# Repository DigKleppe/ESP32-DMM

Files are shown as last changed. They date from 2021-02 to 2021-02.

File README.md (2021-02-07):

# ESP32-DMM
6 digit DMM using ESP32 module
This DMM uses an ESP32 WRoom module as base of the system.
The ADC is a 24 bit ADS1256. The user interface is a 2.8'' TFT and 12 capacitive touchbuttons.
A frontend for voltage, current and Ohms completes the design.
The volts/ohms input is protected for 500V.
The current input has a fuse.

Specifications:
DC/AC true RMS, 10ME input resistance.
Voltage: 250mV - 500V 5 ranges;
Current: 10uA-10A 6 ranges;
Resistance: 1E - 20M, 5 ranges.

The accuracy is targetted at better than 0.1%.
Speed: for hi resolution ( 5-6 digits): 2 readings per second.
For lower resolutions 5 -10 readings per second.

Despite the use of some Aliexpress modules like the ADC ADS1256, it has become a
rather complex design. Not for beginners i suppose.

Remark about the resistors: 0.1% thin film resistors are used. These have better noise preformance.

One of the issues is calibrating, you need a accurate DVM for this.
The calibrating itself is done using a webserver. The calibration data can be up/downloaded
to a host. 

Status of the project 02-21:
Second version. New schematics and PCB, contains corrections of the first prototype. Also better screening to reduce noise.
Not tested yet.
Software: todo: make some changes io-ports.

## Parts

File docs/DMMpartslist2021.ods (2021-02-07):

Ref | Qnty | Value | Cmp name | Footprint | Description | Digikey | Mouser
ACDC1, | 1 | RAC10-15DK | RAC10-12DK | klp:RAC10 | Recom AC/DC converter 10W |  | 919-RAC10-05SK/277
ACDC2, | 1 | RAC10-05SK/277 | RAC10-12DK | klp:RAC10 | Recom AC/DC converter 10W |  | 919-RAC10-15DK/277
C1, C2, C9, C10, C15, C16, C17, C19, C20, C21, C23, C25, C26, C27, C29, C40, C41, C42, | 18 | 100n | C | Capacitor_SMD:C_0805_2012Metric_Pad1.15x1.40mm_HandSolder | Unpolarized capacitor
C11, C12, C30, C31, C36, | 5 | 1u | C | Capacitor_SMD:C_0805_2012Metric_Pad1.15x1.40mm_HandSolder | Unpolarized capacitor
C13, C14, C39, | 3 | 10uV16 | CP | Capacitor_THT:CP_Radial_D5.0mm_P2.00mm | Polarized capacitor
C32, | 1 | 2n2 Y2 | C | Capacitor_THT:C_Rect_L13.0mm_W4.0mm_P10.00mm_FKS3_FKP3_MKS4 | Unpolarized capacitor
C33, | 1 | 290p | C | Capacitor_THT:C_Disc_D3.0mm_W2.0mm_P2.50mm | Unpolarized capacitor
C37, | 1 | 10n | C | Capacitor_SMD:C_0805_2012Metric_Pad1.15x1.40mm_HandSolder | Unpolarized capacitor
C38, | 1 | 330p | C | Capacitor_SMD:C_0805_2012Metric_Pad1.15x1.40mm_HandSolder | Unpolarized capacitor
D1, D11, D12, D13, D16, D17, | 6 | BAT754S | BAT754S | klp:SOT-23-handsolder | Dual schottky barrier diode, in series, SOT-323 |  | 771-BAT754-T/R
D2, | 1 | CMKD6001 | Central_Semi_CMKD6001 | Package_TO_SOT_SMD:SOT-363_SC-70-6 | Ultra low leakage switching diode array 3 independent | 1514-CMKD6001TRPBFREECT-ND
D6, D7, | 2 | APT30DQ60KG | D | Package_TO_SOT_THT:TO-220-2_Vertical | Diode | 494-APT30DQ60KG
D8, D9, | 2 | G | LED_ALT | LED_SMD:LED_0805_2012Metric_Pad1.15x1.40mm_HandSolder | Light emitting diode, filled shape
D10, | 1 | 1.5SMC6.8A | Z3SMCxxx | Diode_SMD:D_SMC | 3000mW Zener Diode, SMC(DO-214AB)
F1, | 1 | PTCCL05H100SBE | Polyfuse | klp:PTCCL05H100SBE | Resettable fuse, polymeric positive temperature coefficient | BC3368-ND
F2, | 1 | Fuse | Fuse | Fuse:Fuseholder_Cylinder-5x20mm_Stelvio-Kontek_PTF78_Horizontal_Open | Fuse
J1, J2, J3, | 3 | Conn_01x01 | Conn_01x01 | klp:bananajack-5p | Generic connector, single row, 01x01, script generated (kicad-library-utils/schlib/autogen/connector/) |  |  | https://www.aliexpress.com/snapshot/0.html?orderId=3008924834401255&productId=32822244065
J4, | 1 | Conn_01x06 | Conn_01x04 | Connector_Phoenix_MSTB:PhoenixContact_MSTBVA_2,5_4-G_1x04_P5.00mm_Vertical | Generic connector, single row, 01x04, script generated (kicad-library-utils/schlib/autogen/connector/)
J5, | 1 | bozed header 6p | Conn_02x03_Odd_Even | Connector_IDC:IDC-Header_2x03_P2.54mm_Vertical | Generic connector, double row, 02x03, odd/even pin numbering scheme (row 1 odd numbers, row 2 even numbers), script generated (kicad-library-utils/schlib/autogen/connector/)
J6, J9, | 2 | boxed header 2x5 | Conn_02x05_Odd_Even | Connector_IDC:IDC-Header_2x05_P2.54mm_Vertical | Generic connector, double row, 02x05, odd/even pin numbering scheme (row 1 odd numbers, row 2 even numbers), script generated (kicad-library-utils/schlib/autogen/connector/)
J7, | 1 | Conn_01x06 | Conn_01x06 | Connector_PinHeader_2.54mm:PinHeader_1x06_P2.54mm_Vertical | Generic connector, single row, 01x06, script generated (kicad-library-utils/schlib/autogen/connector/)
J8, | 1 | Conn_02x10_Odd_Even | Conn_02x10_Odd_Even | Connector_IDC:IDC-Header_2x10_P2.54mm_Vertical | Generic connector, double row, 02x10, odd/even pin numbering scheme (row 1 odd numbers, row 2 even numbers), script generated (kicad-library-utils/schlib/autogen/connector/)
J12, | 1 | Conn_01x02 | Conn_01x02 | Connector_Phoenix_MSTB:PhoenixContact_MSTBVA_2,5_2-G_1x02_P5.00mm_Vertical | Generic connector, single row, 01x02, script generated (kicad-library-utils/schlib/autogen/connector/)
K2, | 1 | Coto 9104-05-10 | Coto_9104-05-10_SIL_reedrelay | klp:Relay_SPST_Coto_9104_SIL | Coto_9104-05-10_SIL reed relay, SPST, Closing Contact | 306-1193-ND
M1, | 1 | LTC1966module | LTC1966module | klp:ltc1966module | true RMS converter CJMCU-6668 |  |  | https://nl.aliexpress.com/item/4000428797754.html?spm=a2g0s.9042311.0.0.235b4c4dVnynwd
M2, | 1 | ADS1256module | ADS1256module | klp:ADS1256module |  |  |  | https://nl.aliexpress.com/item/32762202652.html?spm=a2g0s.9042311.0.0.235b4c4dVnynwd
Q1, Q2, Q3, Q4, Q5, Q6, | 6 | IRFB7437PbF | Q_NMOS_GDS | Package_TO_SOT_THT:TO-220-3_Vertical | N-MOSFET transistor, gate/drain/source
Q7, | 1 | BSS138 | BSS138 | Package_TO_SOT_SMD:SOT-23 | 50V Vds, 0.22A Id, N-Channel MOSFET, SOT-23
R1, R2, R3, R4, R5, R6, R9, R12, R15, R18, | 10 | 2M | R | Resistor_SMD:R_1206_3216Metric_Pad1.42x1.75mm_HandSolder | Resistor | 541-TNPW12062M00BEEACT-ND
R7, R10, R13, R16, | 4 | 105k | R | Resistor_SMD:R_1206_3216Metric_Pad1.42x1.75mm_HandSolder | Resistor | A140961CT-ND
R8, R11, R14, R17, R30, R35, | 6 | 10k | R | Resistor_SMD:R_1206_3216Metric_Pad1.42x1.75mm_HandSolder | Resistor | A140952CT-ND
R19, R67, R70, | 3 | 100k | R | Resistor_SMD:R_0805_2012Metric_Pad1.15x1.40mm_HandSolder | Resistor | P100KDACT-ND
R20, | 1 | 200k | R | Resistor_SMD:R_0805_2012Metric_Pad1.15x1.40mm_HandSolder | Resistor | P200KDACT-ND
R21, | 1 | 22k | R | Resistor_SMD:R_0805_2012Metric_Pad1.15x1.40mm_HandSolder | Resistor | P22KDACT-ND
R22, R37, R38, R47, R48, R73, | 6 | 2k | R | Resistor_SMD:R_0805_2012Metric_Pad1.15x1.40mm_HandSolder | Resistor | P2KDACT-ND
R23, | 1 | 200E | R | Resistor_SMD:R_0805_2012Metric_Pad1.15x1.40mm_HandSolder | Resistor | P200DACT-ND
R25, R28, R36, R66, R72, R74, | 6 | 10k | R | Resistor_SMD:R_0805_2012Metric_Pad1.15x1.40mm_HandSolder | Resistor | P10KDACT-ND
R26, | 1 | 100mE | R | klp:2818kelvin | Resistor | 541-3282-1-ND
R27, | 1 | 10mE | R | klp:2818kelvin | Resistor | 541-3276-1-ND
R29, | 1 | 1mE | R | klp:2818kelvin | Resistor | 541-3272-1-ND
R31, R32, R33, R34, | 4 | 1k | R | Resistor_SMD:R_1206_3216Metric_Pad1.42x1.75mm_HandSolder | Resistor 1% 1206
R39, R40, R41, R42, R63, | 5 | 100E | R | Resistor_SMD:R_0805_2012Metric_Pad1.15x1.40mm_HandSolder | Resistor 1% 1206
R43, R44, R45, R46, | 4 | 33E | R | Resistor_SMD:R_0805_2012Metric_Pad1.15x1.40mm_HandSolder | Resistor 1% 1206
R49, R50, R54, R57, R61, R65, | 6 | 1k5 | R | Resistor_SMD:R_0805_2012Metric_Pad1.15x1.40mm_HandSolder | Resistor | P1.5KDACT-ND
R51, R55, R56, R62, | 4 | 1k | R | Resistor_SMD:R_0805_2012Metric_Pad1.15x1.40mm_HandSolder | Resistor | P1.0KDACT-ND
R52, | 1 | 9k | R | Resistor_SMD:R_0805_2012Metric_Pad1.15x1.40mm_HandSolder | Resistor | P9.0KDACT-ND
R64, R71, | 2 | 100+100k | matched_dualR | Package_TO_SOT_SMD:SOT-23 |  |  | 71-MPMT2003AT1
R68, | 1 | 1M | R | Resistor_SMD:R_0805_2012Metric_Pad1.15x1.40mm_HandSolder | Resistor | P1MDACT-ND
R69, | 1 | 10M | R | Resistor_SMD:R_0805_2012Metric_Pad1.15x1.40mm_HandSolder | Resistor | 749-1744-1-ND
SW1, | 1 | SW_SPST | SW_SPST | Button_Switch_THT:SW_PUSH_6mm | Single Pole Single Throw (SPST) switch
TH1, | 1 | 10k | Thermistor_NTC | Resistor_THT:R_Axial_DIN0204_L3.6mm_D1.6mm_P2.54mm_Vertical | Temperature dependent resistor, negative temperature coefficient
U1, U3, | 2 | ADG1414 | ADG1414 | Package_SO:TSSOP-24_4.4x7.8mm_P0.65mm | octal analog +-15V switch SPI |  | 584-ADG1414BRUZ
U2, U10, U11, U12, | 4 | OPA2182ID | OPA2182ID | Package_SO:SO-8_3.9x4.9mm_P1.27mm | dual zero offset opamp 36V |  | 595-OPA2182IDR
U4, | 1 | TD310 | TD310 | Package_SO:SOIC-16_3.9x9.9mm_P1.27mm | 3 channel low side FET driver |  | 497-6756-5-ND
U5, | 1 | INA213 | INA210 | klp:Texas_R_PDSO-G6 | current sens amplifier |  | 296-26072-1-ND
U6, | 1 | L78L12_SO8 | MC78L05_SO8 | Package_SO:SOIC-8_3.9x4.9mm_P1.27mm | Positive 100mA 30V Linear Regulator, Fixed Output 5V, SO-8
U8, | 1 | L79L12_SO8 | L79L05_SO8 | Package_SO:SOIC-8_3.9x4.9mm_P1.27mm | Negative 100mA -30V Linear Regulator, Fixed Output -5V, SO-8
U9, | 1 | NCP1117-3.3_TO252 | NCP1117-3.3_TO252 | Package_TO_SOT_SMD:TO-252-2 | 1A Low drop-out regulator, Fixed Output 3.3V, TO-252 (DPAK)
U15, | 1 | LM339 | LM339 | Package_SO:SOIC-14_3.9x8.7mm_P1.27mm | Quad Differential Comparators, DIP-14/SOIC-14/SSOP-14
U16, | 1 | ESP32-WROOM | ESP32-WROOM | ESP32:ESP32-WROOM |  |  | 356-ESP32WRM32E128PH
 |  | ABS housing 230x210x86 | BDH20014 | https://nl.aliexpress.com/item/32901775288.html?spm=a2g0s.9042311.0.0.235b4c4dVnynwd

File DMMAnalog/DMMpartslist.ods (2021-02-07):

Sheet: DMM
Ref | Qnty | Value | Cmp name | Footprint | Description | Digikey | Mouser
C1. | 1 | 10n | C | Capacitor_THT:C_Disc_D3.0mm_W2.0mm_P2.50mm | Unpolarized capacitor |  |  | 0.00 €
C2. | 1 | 3p9 | C | Capacitor_THT:C_Disc_D3.0mm_W2.0mm_P2.50mm | Unpolarized capacitor |  |  | 0.00 €
C3. C4. C5. C6. C7. C8. C9. C10. | 8 | C | C | Capacitor_THT:C_Rect_L7.0mm_W6.0mm_P5.00mm | Unpolarized capacitor |  |  | 0.00 €
C16. C17. C18. C19. C20. C21. C22. C24. C32. C33. C34. C35. C36. C37. C38. C39. C40. C41. C42. C43. C44. C45. C46. C47. C48. C49. C50. C51. | 28 | 100n | C | Capacitor_SMD:C_0805_2012Metric_Pad1.15x1.40mm_HandSolder | Unpolarized capacitor |  |  | 0.00 €
J2. | 1 | Conn_01x02 | Conn_01x02 | Connector_Phoenix_MSTB:PhoenixContact_MSTBVA_2.5_2-G_1x02_P5.00mm_Vertical | Generic connector. single row. 01x02. script generated (kicad-library-utils/schlib/autogen/connector/) |  |  | 0.00 €
J4. | 1 | bozed header 6p | Conn_02x03_Odd_Even | Connector_IDC:IDC-Header_2x03_P2.54mm_Vertical | Generic connector. double row. 02x03. odd/even pin numbering scheme (row 1 odd numbers. row 2 even numbers). script generated (kicad-library-utils/schlib/autogen/connector/) |  |  | 0.00 €
J5. J7. | 2 | boxed header 2x5 | Conn_02x05_Odd_Even | Connector_IDC:IDC-Header_2x05_P2.54mm_Vertical | Generic connector. double row. 02x05. odd/even pin numbering scheme (row 1 odd numbers. row 2 even numbers). script generated (kicad-library-utils/schlib/autogen/connector/) |  |  | 0.00 €
J6. | 1 | Conn_01x06 | Conn_01x06 | Connector_PinHeader_2.54mm:PinHeader_1x06_P2.54mm_Vertical | Generic connector. single row. 01x06. script generated (kicad-library-utils/schlib/autogen/connector/) |  |  | 0.00 €
R3. R46. R47. R48. R49. R50. R53. R54. R55. | 9 | 100E | R | Resistor_SMD:R_1206_3216Metric_Pad1.42x1.75mm_HandSolder | Resistor |  |  | 0.00 €
R33. | 1 | 33E | R | Resistor_SMD:R_1206_3216Metric_Pad1.42x1.75mm_HandSolder | Resistor |  |  | 0.00 €
SW1. | 1 | SW_SPST | SW_SPST | Button_Switch_THT:SW_PUSH_6mm | Single Pole Single Throw (SPST) switch |  |  | 0.00 €
TH1. | 1 | 10k | Thermistor_NTC | Resistor_THT:R_Axial_DIN0204_L3.6mm_D1.6mm_P2.54mm_Vertical | Temperature dependent resistor. negative temperature coefficient |  |  | 0.00 €
TP1. TP2. TP3. TP4. TP5. TP6. TP7. TP8. TP9. TP10. TP11. TP12. TP13. TP14. TP15. TP16. TP17. TP18. TP19. TP20. TP21. TP22. TP23. TP24. TP25. TP26. TP27. TP28. TP29. TP30. TP31. TP32. TP33. TP34. TP35. | 35 | TestPoint | TestPoint | TestPoint:TestPoint_THTPad_2.0x2.0mm_Drill1.0mm | test point |  |  | 0.00 €
U10. | 1 | L78L12_SO8 | L78L05_SO8 | Package_SO:SOIC-8_3.9x4.9mm_P1.27mm | Positive 100mA 30V Linear Regulator. Fixed Output 5V. SO-8 |  |  | 0.00 €
U11. | 1 | L79L12_SO8 | L79L05_SO8 | Package_SO:SOIC-8_3.9x4.9mm_P1.27mm | Negative 100mA -30V Linear Regulator. Fixed Output -5V. SO-8 |  |  | 0.00 €
U12. | 1 | NCP1117-3.3_TO252 | NCP1117-3.3_TO252 | Package_TO_SOT_SMD:TO-252-2 | 1A Low drop-out regulator. Fixed Output 3.3V. TO-252 (DPAK) |  |  | 0.00 €
U15. | 1 | LM358 | LM358 | Package_SO:SO-8_3.9x4.9mm_P1.27mm | Low-Power. Dual Operational Amplifiers. DIP-8/SOIC-8/TO-99-8 |  |  | 0.00 €

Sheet: Mouser
amount | value | PN
1 | RAC10-12DK | 919-RAC10-12DK/277 | 9.14 € | € 9.14
1 | RAC10-05SK/277 | 919-RAC10-05SK/277 | 9.14 € | € 9.14
5 | BAT754S | 771-BAT754-T/R | 0.32 € | € 0.96
4 | APT30DQ60KG | 494-APT30DQ60KG | 0.58 € | € 1.16
2 | 100+100k | 71-MPMT2003AT1 | 3.02 € | € 6.04
3 | 1k+9k | 71-MPMT10019001AT1 | 3.43 € | € 10.29
8 | OPA2182ID | 595-OPA2182IDR | 2.87 € | € 17.22
3 | ADG1414 | 584-ADG1414BRUZ | 6.91 € | € 20.73
1 | ESP32-WROOM | 356-ESP32WRM32E128PH | 2.62 € | € 2.62
1 | ESP prog | 356-ESP-PROG | 11.11 € | € 11.11
1 | 8u2 capacitor | 667-ECQ-E1825KFB | 2.14 | € 13.11
total |  |  |  | € 101.52

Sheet: Digikey
Qnty | Value | Description |  | PN
6 | 1u | Unpolarized capacitor |  | P14633-ND | 0.74 € | 4.44 €
3 | 10u | Unpolarized capacitor |  | P14629-ND | 2.20 € | 6.60 €
10 | BAS116 | Diode |  | 1727-6374-1-ND | 0.18 € | 1.80 €
6 | IRFB7437PbF | N-MOSFET transistor. drain/gate/source |  | IRFB7437PBF-ND | 1.17 € | 7.02 €
5 | 1k5 | Resistor |  | P1.5KDACT-ND | 0.33 € | 1.65 €
10 | 1k | Resistor |  | P1.0KDACT-ND | 0.33 € | 3.30 €
5 | 10k | Resistor |  | P10KDACT-ND | 0.33 € | 1.65 €
5 | 100k | Resistor |  | P100KDACT-ND | 0.33 € | 1.65 €
5 | 1M | Resistor |  | P1MDACT-ND | 0.33 € | 1.65 €
5 | 10M | Resistor |  | 749-1744-1-ND | 0.31 € | 1.55 €
15 | 2M | Resistor |  | 541-TNPW12062M00BEEACT-ND | 0.65 € | 9.75 €
2 | 100k | Resistor |  | 541-TNPW1206100KBETACT-ND | 0.85 € | 1.70 €
5 | 330k | Resistor |  | P330KDACT-ND | 0.33 € | 1.65 €
5 | 220k | Resistor |  | P220KDACT-ND | 0.33 € | 1.65 €
5 | 20k | Resistor |  | P20KDACT-ND | 0.33 € | 1.65 €
5 | 2k | Resistor |  | P2KDACT-ND | 0.33 € | 1.65 €
5 | 200E | Resistor |  | P200DACT-ND | 0.33 € | 1.65 €
1 | 100mE | Resistor |  | 541-3282-1-ND | 1.43 € | 1.43 €
1 | 10mE | Resistor |  | 541-3276-1-ND | 1.43 € | 1.43 €
1 | 1mE | Resistor |  | 541-3272-1-ND | 1.89 € | 1.89 €
5 | 53k6 | Resistor |  | P53.6KDACT-ND | 0.28 € | 1.40 €
5 | 3k16 | Resistor |  | P3.16KDACT-ND | 0.28 € | 1.40 €
1 | TD310 | 3 channel low side FET driver |  | 497-6756-5-ND | 1.22 € | 1.22 €
1 | INA213 | current sens amplifier |  | 296-26072-1-ND | 1.10 € | 1.10 €
1 | reed relay |  |  | 7201-05-1100 | 33.92 € | 33.92 €
2 | polyfuse |  |  | BC3368-ND | 1.03 | 2.06 €
2 | 79L12 |  |  | 296-31679-1-ND | 0.36 € | 0.72 €
2 | 78L12 |  |  | 497-1194-1-ND | 0.35 € | 0.70 €
1 |  |  | tvs diode | 1.5SMC6.8A-E3/57TGITR-ND | 0.22 € | 0.22 €
 | 1.5SMC6.8A |  |  |  |  | 0.00 €
total |  |  |  |  |  | 97.58 €
5 | 10k |  |  | A140952CT-ND | 0.73 € | 3.65 € | 0.10% | 10ppm
5 | 105k |  |  | A140961CT-ND | 0.73 € | 3.65 €

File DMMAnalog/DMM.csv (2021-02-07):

Source: | /home/dig/Desktop/DMM/hardware/DMMAnalog/DMM.sch
Date: | zo 07 feb 2021 13:01:57 CET
Tool: | Eeschema 5.1.7-a382d34a8~87~ubuntu18.04.1
Generator: | /usr/share/kicad/plugins/bom_csv_grouped_by_value_with_fp.py
Component Count: | 218
Ref | Qnty | Value | Cmp name | Footprint | Description | Vendor
ACDC1, | 1 | RAC10-15DK | RAC10-12DK | klp:RAC10 | Recom AC/DC converter 10W
ACDC2, | 1 | RAC10-05SK/277 | RAC10-12DK | klp:RAC10 | Recom AC/DC converter 10W
C1, C2, C9, C10, C15, C16, C17, C19, C20, C21, C23, C25, C26, C27, C29, C40, C41, C42, | 18 | 100n | C | Capacitor_SMD:C_0805_2012Metric_Pad1.15x1.40mm_HandSolder | Unpolarized capacitor
C11, C12, C30, C31, C36, | 5 | 1u | C | Capacitor_SMD:C_0805_2012Metric_Pad1.15x1.40mm_HandSolder | Unpolarized capacitor
C13, C14, C39, | 3 | 10uV16 | CP | Capacitor_THT:CP_Radial_D5.0mm_P2.00mm | Polarized capacitor
C32, | 1 | 2n2 Y2 | C | Capacitor_THT:C_Rect_L13.0mm_W4.0mm_P10.00mm_FKS3_FKP3_MKS4 | Unpolarized capacitor
C33, | 1 | 290p | C | Capacitor_THT:C_Disc_D3.0mm_W2.0mm_P2.50mm | Unpolarized capacitor
C37, | 1 | 10n | C | Capacitor_SMD:C_0805_2012Metric_Pad1.15x1.40mm_HandSolder | Unpolarized capacitor
C38, | 1 | 330p | C | Capacitor_SMD:C_0805_2012Metric_Pad1.15x1.40mm_HandSolder | Unpolarized capacitor
D1, D11, D12, D13, D16, D17, | 6 | BAT754S | BAT754S | klp:SOT-23-handsolder | Dual schottky barrier diode, in series, SOT-323
D2, | 1 | CMKD6001 | Central_Semi_CMKD6001 | Package_TO_SOT_SMD:SOT-363_SC-70-6 | Ultra low leakage switching diode array 3 independent
D6, D7, | 2 | APT30DQ60KG | D | Package_TO_SOT_THT:TO-220-2_Vertical | Diode
D8, D9, | 2 | G | LED_ALT | LED_SMD:LED_0805_2012Metric_Pad1.15x1.40mm_HandSolder | Light emitting diode, filled shape
D10, | 1 | 1.5SMC6.8A | Z3SMCxxx | Diode_SMD:D_SMC | 3000mW Zener Diode, SMC(DO-214AB)
F1, | 1 | PTCCL05H100SBE | Polyfuse | klp:PTCCL05H100SBE | Resettable fuse, polymeric positive temperature coefficient
F2, | 1 | Fuse | Fuse | Fuse:Fuseholder_Cylinder-5x20mm_Stelvio-Kontek_PTF78_Horizontal_Open | Fuse
H1, H2, H3, H4, H5, H6, H7, H8, H9, H10, H11, H12, H13, H14, H15, H16, H17, H18, H19, H20, H21, H22, H23, H24, | 24 | MountingHole | MountingHole | MountingHole:MountingHole_3.1mm_M3 | Mounting Hole without connection
H26, H27, H28, H29, H30, | 5 | MountingHole_Pad | MountingHole_Pad | MountingHole:MountingHole_3.2mm_M3_DIN965_Pad | Mounting Hole with connection
J1, J2, J3, | 3 | Conn_01x01 | Conn_01x01 | klp:bananajack-5p | Generic connector, single row, 01x01, script generated (kicad-library-utils/schlib/autogen/connector/)
J4, | 1 | Conn_01x06 | Conn_01x04 | Connector_Phoenix_MSTB:PhoenixContact_MSTBVA_2,5_4-G_1x04_P5.00mm_Vertical | Generic connector, single row, 01x04, script generated (kicad-library-utils/schlib/autogen/connector/)
J5, | 1 | bozed header 6p | Conn_02x03_Odd_Even | Connector_IDC:IDC-Header_2x03_P2.54mm_Vertical | Generic connector, double row, 02x03, odd/even pin numbering scheme (row 1 odd numbers, row 2 even numbers), script generated (kicad-library-utils/schlib/autogen/connector/)
J6, J9, | 2 | boxed header 2x5 | Conn_02x05_Odd_Even | Connector_IDC:IDC-Header_2x05_P2.54mm_Vertical | Generic connector, double row, 02x05, odd/even pin numbering scheme (row 1 odd numbers, row 2 even numbers), script generated (kicad-library-utils/schlib/autogen/connector/)
J7, | 1 | Conn_01x06 | Conn_01x06 | Connector_PinHeader_2.54mm:PinHeader_1x06_P2.54mm_Vertical | Generic connector, single row, 01x06, script generated (kicad-library-utils/schlib/autogen/connector/)
J8, | 1 | Conn_02x10_Odd_Even | Conn_02x10_Odd_Even | Connector_IDC:IDC-Header_2x10_P2.54mm_Vertical | Generic connector, double row, 02x10, odd/even pin numbering scheme (row 1 odd numbers, row 2 even numbers), script generated (kicad-library-utils/schlib/autogen/connector/)
J12, | 1 | Conn_01x02 | Conn_01x02 | Connector_Phoenix_MSTB:PhoenixContact_MSTBVA_2,5_2-G_1x02_P5.00mm_Vertical | Generic connector, single row, 01x02, script generated (kicad-library-utils/schlib/autogen/connector/)
K1, | 1 | reedrelayboard | reedrelayboard | klp:reedRelayBoard | Coto reed relay, SPDT
K2, | 1 | Coto 9104-05-10 | Coto_9104-05-10_SIL_reedrelay | klp:Relay_SPST_Coto_9104_SIL | Coto_9104-05-10_SIL reed relay, SPST, Closing Contact
M1, | 1 | LTC1966module | LTC1966module | klp:ltc1966module | true RMS converter
M2, | 1 | ADS1256module | ADS1256module | klp:ADS1256module
Q1, Q2, Q3, Q4, Q5, Q6, | 6 | IRFB7437PbF | Q_NMOS_GDS | Package_TO_SOT_THT:TO-220-3_Vertical | N-MOSFET transistor, gate/drain/source
Q7, | 1 | BSS138 | BSS138 | Package_TO_SOT_SMD:SOT-23 | 50V Vds, 0.22A Id, N-Channel MOSFET, SOT-23
R1, R2, R3, R4, R5, R6, R9, R12, R15, R18, | 10 | 2M | R | Resistor_SMD:R_1206_3216Metric_Pad1.42x1.75mm_HandSolder | Resistor
R7, R10, R13, R16, | 4 | 105k | R | Resistor_SMD:R_1206_3216Metric_Pad1.42x1.75mm_HandSolder | Resistor
R8, R11, R14, R17, R30, R35, | 6 | 10k | R | Resistor_SMD:R_1206_3216Metric_Pad1.42x1.75mm_HandSolder | Resistor
R19, R67, R70, | 3 | 100k | R | Resistor_SMD:R_0805_2012Metric_Pad1.15x1.40mm_HandSolder | Resistor
R20, | 1 | 200k | R | Resistor_SMD:R_0805_2012Metric_Pad1.15x1.40mm_HandSolder | Resistor
R21, | 1 | 22k | R | Resistor_SMD:R_0805_2012Metric_Pad1.15x1.40mm_HandSolder | Resistor
R22, R37, R38, R47, R48, R73, | 6 | 2k | R | Resistor_SMD:R_0805_2012Metric_Pad1.15x1.40mm_HandSolder | Resistor
R23, | 1 | 200E | R | Resistor_SMD:R_0805_2012Metric_Pad1.15x1.40mm_HandSolder | Resistor
R25, R28, R36, R66, R72, R74, | 6 | 10k | R | Resistor_SMD:R_0805_2012Metric_Pad1.15x1.40mm_HandSolder | Resistor
R26, | 1 | 100mE | R | klp:2818kelvin | Resistor
R27, | 1 | 10mE | R | klp:2818kelvin | Resistor
R29, | 1 | 1mE | R | klp:2818kelvin | Resistor
R31, R32, R33, R34, | 4 | 1k | R | Resistor_SMD:R_1206_3216Metric_Pad1.42x1.75mm_HandSolder | Resistor
R39, R40, R41, R42, R63, | 5 | 100E | R | Resistor_SMD:R_0805_2012Metric_Pad1.15x1.40mm_HandSolder | Resistor
R43, R44, R45, R46, | 4 | 33E | R | Resistor_SMD:R_0805_2012Metric_Pad1.15x1.40mm_HandSolder | Resistor
R49, R50, R54, R57, R61, R65, | 6 | 1k5 | R | Resistor_SMD:R_0805_2012Metric_Pad1.15x1.40mm_HandSolder | Resistor
R51, R55, R56, R62, | 4 | 1k | R | Resistor_SMD:R_0805_2012Metric_Pad1.15x1.40mm_HandSolder | Resistor
R52, | 1 | 9k | R | Resistor_SMD:R_0805_2012Metric_Pad1.15x1.40mm_HandSolder | Resistor
R64, R71, | 2 | 100+100k | matched_dualR | Package_TO_SOT_SMD:SOT-23
R68, | 1 | 1M | R | Resistor_SMD:R_0805_2012Metric_Pad1.15x1.40mm_HandSolder | Resistor
R69, | 1 | 10M | R | Resistor_SMD:R_0805_2012Metric_Pad1.15x1.40mm_HandSolder | Resistor
SW1, | 1 | SW_SPST | SW_SPST | Button_Switch_THT:SW_PUSH_6mm | Single Pole Single Throw (SPST) switch
TH1, | 1 | 10k | Thermistor_NTC | Resistor_THT:R_Axial_DIN0204_L3.6mm_D1.6mm_P2.54mm_Vertical | Temperature dependent resistor, negative temperature coefficient
TP1, TP2, TP3, TP4, TP5, TP6, TP7, TP8, TP9, TP10, TP11, TP12, TP13, TP14, TP15, TP16, TP17, TP18, TP19, TP20, TP21, TP22, TP23, TP24, TP30, TP31, TP32, TP33, TP34, TP35, TP36, TP37, TP38, TP39, TP40, TP41, TP42, | 37 | TestPoint | TestPoint | TestPoint:TestPoint_THTPad_2.0x2.0mm_Drill1.0mm | test point
U1, U3, | 2 | ADG1414 | ADG1414 | Package_SO:TSSOP-24_4.4x7.8mm_P0.65mm | octal analog +-15V switch SPI
U2, U10, U11, U12, | 4 | OPA2182ID | OPA2182ID | Package_SO:SO-8_3.9x4.9mm_P1.27mm | dual zero offset opamp 36V
U4, | 1 | TD310 | TD310 | Package_SO:SOIC-16_3.9x9.9mm_P1.27mm | 3 channel low side FET driver
U5, | 1 | INA213 | INA210 | klp:Texas_R_PDSO-G6 | current sens amplifier
U6, | 1 | L78L12_SO8 | MC78L05_SO8 | Package_SO:SOIC-8_3.9x4.9mm_P1.27mm | Positive 100mA 30V Linear Regulator, Fixed Output 5V, SO-8
U8, | 1 | L79L12_SO8 | L79L05_SO8 | Package_SO:SOIC-8_3.9x4.9mm_P1.27mm | Negative 100mA -30V Linear Regulator, Fixed Output -5V, SO-8
U9, | 1 | NCP1117-3.3_TO252 | NCP1117-3.3_TO252 | Package_TO_SOT_SMD:TO-252-2 | 1A Low drop-out regulator, Fixed Output 3.3V, TO-252 (DPAK)
U15, | 1 | LM339 | LM339 | Package_SO:SOIC-14_3.9x8.7mm_P1.27mm | Quad Differential Comparators, DIP-14/SOIC-14/SSOP-14
U16, | 1 | ESP32-WROOM | ESP32-WROOM | ESP32:ESP32-WROOM
U17, | 1 | 2.2_240x320_sd_spi | 2.2_240x320_sd_spi | tft_displays:2.2_tft_240x320_sd_spi

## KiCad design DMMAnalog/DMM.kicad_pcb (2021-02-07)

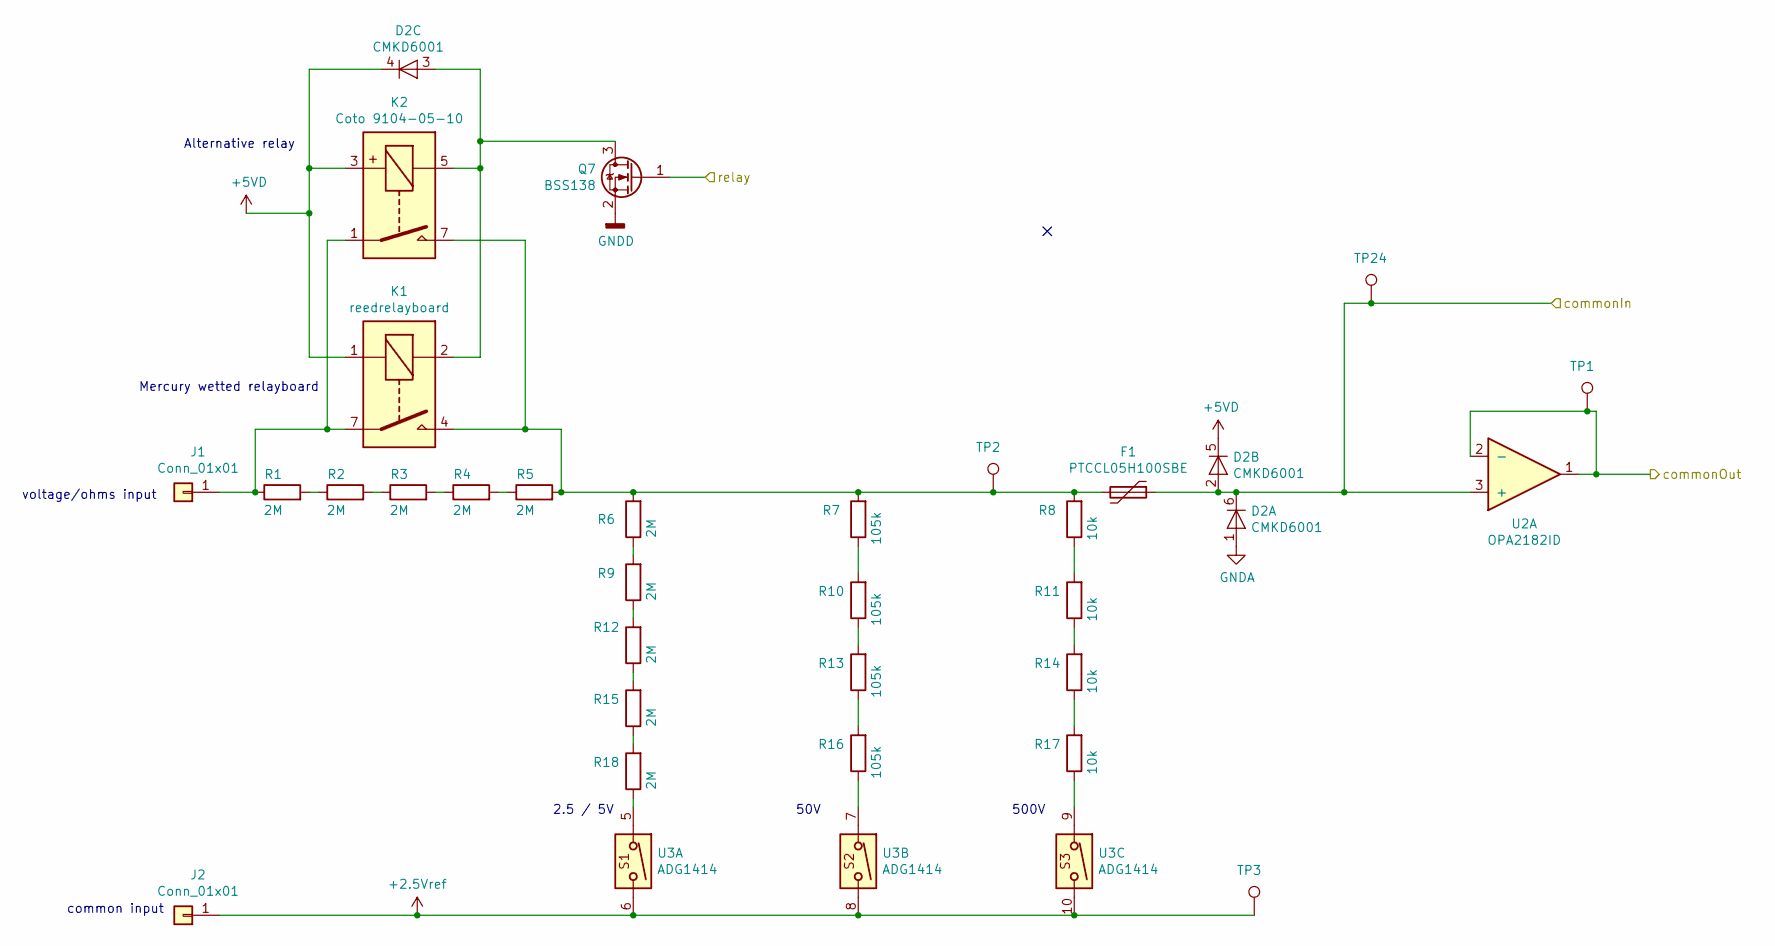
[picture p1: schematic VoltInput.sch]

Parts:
D2: CMKD6001; SOT-363_SC-70-6
F1: PTCCL05H100SBE
J1, J2: Conn_01x01; bananajack-5p
K1: reedrelayboard; reedRelayBoard
K2: Coto 9104-05-10; Relay_SPST_Coto_9104_SIL
Q7: BSS138; SOT-23
R1, R2, R3, R4, R5, R6, R9, R12, R15, R18: 2M; R_1206_3216Metric_Pad1.42x1.75mm_HandSolder
R7, R10, R13, R16: 105k; R_1206_3216Metric_Pad1.42x1.75mm_HandSolder
R8, R11, R14, R17: 10k; R_1206_3216Metric_Pad1.42x1.75mm_HandSolder
TP1, TP2, TP3, TP24: TestPoint; TestPoint_THTPad_2.0x2.0mm_Drill1.0mm
U2: OPA2182ID; SO-8_3.9x4.9mm_P1.27mm
U3: ADG1414; TSSOP-24_4.4x7.8mm_P0.65mm

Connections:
+1V0: J2.1, TP3.1, U3.6, U3.8, U3.10; also elsewhere on the board
+5VD: D2.4 (K), D2.5 (K), K1.1, K2.3; also elsewhere on the board
/ESP32/relay: Q7.1 (G); also elsewhere on the board
/VoltInput/commonIn: D2.2 (A), D2.6 (K), F1.1, TP24.1, U2.3 (+); also elsewhere on the board
/filter-amplifier/amp-in: TP1.1, U2.1, U2.2 (-); also elsewhere on the board
GNDA: D2.1 (A); also elsewhere on the board
GNDD: Q7.2 (S); also elsewhere on the board
unnamed: D2.3 (A), K1.2, K2.5, Q7.3 (D)
unnamed: F1.2, K1.4, K2.7, R5.2, R6.2, R7.2, R8.2, TP2.1
unnamed: J1.1, K1.7, K2.1, R1.1
unnamed: R1.2, R2.1
unnamed: R2.2, R3.1
unnamed: R3.2, R4.1
unnamed: R4.2, R5.1
unnamed: R6.1, R9.2
unnamed: R10.1, R13.2
unnamed: R7.1, R10.2
unnamed: R11.1, R14.2
unnamed: R8.1, R11.2
unnamed: R12.1, R15.2
unnamed: R9.1, R12.2
unnamed: R13.1, R16.2
unnamed: R14.1, R17.2
unnamed: R15.1, R18.2
unnamed: R16.1, U3.7
unnamed: R17.1, U3.9
unnamed: R18.1, U3.5

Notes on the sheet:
50V
500V
2.5 / 5V
voltage/ohms input
common input
Mercury wetted relayboard
Alternative relay

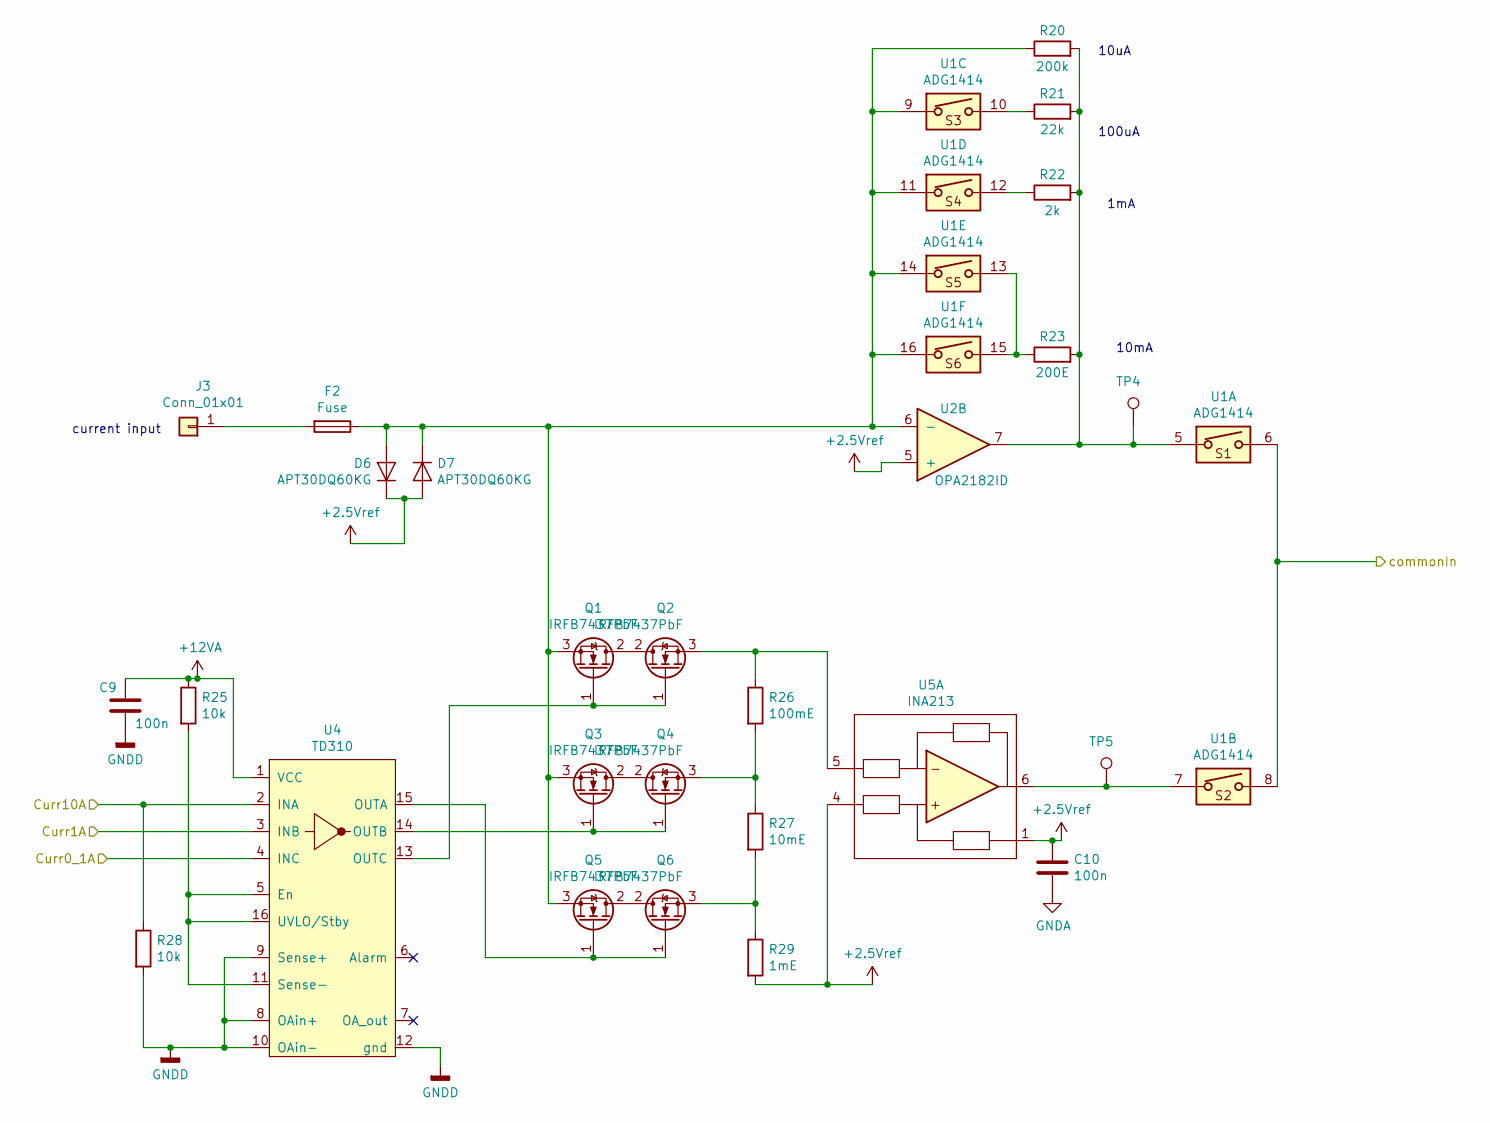
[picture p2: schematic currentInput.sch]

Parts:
C9, C10: 100n; C_0805_2012Metric_Pad1.15x1.40mm_HandSolder
D6, D7: APT30DQ60KG; TO-220-2_Vertical
F2: Fuse; Fuseholder_Cylinder-5x20mm_Stelvio-Kontek_PTF78_Horizontal_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
J3: Conn_01x01; bananajack-5p
Q1, Q2, Q3, Q4, Q5, Q6: IRFB7437PbF; TO-220-3_Vertical
R20: 200k; R_0805_2012Metric_Pad1.15x1.40mm_HandSolder
R21: 22k; R_0805_2012Metric_Pad1.15x1.40mm_HandSolder
R22: 2k; R_0805_2012Metric_Pad1.15x1.40mm_HandSolder
R23: 200E; R_0805_2012Metric_Pad1.15x1.40mm_HandSolder
R25, R28: 10k; R_0805_2012Metric_Pad1.15x1.40mm_HandSolder
R26: 100mE; 2818kelvin
R27: 10mE; 2818kelvin
R29: 1mE; 2818kelvin
TP4, TP5: TestPoint; TestPoint_THTPad_2.0x2.0mm_Drill1.0mm
U1: ADG1414; TSSOP-24_4.4x7.8mm_P0.65mm
U2: OPA2182ID; SO-8_3.9x4.9mm_P1.27mm
U4: TD310; SOIC-16_3.9x9.9mm_P1.27mm
U5: INA213; Texas_R_PDSO-G6

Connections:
+1V0: C10.1, D6.1 (K), D7.2 (A), R29.2, U2.5 (+), U5.1, U5.4; also elsewhere on the board
+12VA: C9.1, R25.1, U4.1 (VCC); also elsewhere on the board
/ESP32/Curr0_1A: U4.4 (INC); also elsewhere on the board
/ESP32/Curr1A: U4.3 (INB); also elsewhere on the board
/ESP32/Curr10A: R28.1, U4.2 (INA); also elsewhere on the board
/VoltInput/commonIn: U1.6, U1.8; also elsewhere on the board
GNDA: C10.2; also elsewhere on the board
GNDD: C9.2, R28.2, U4.8 (OAin+), U4.9 (Sense+), U4.10 (OAin-), U4.12 (gnd); also elsewhere on the board
unnamed: D6.2 (A), D7.1 (K), F2.1, Q1.3 (S), Q3.3 (S), Q5.3 (S), R20.1, U1.9, U1.11, U1.14, U1.16, U2.6 (-)
unnamed: F2.2, J3.1
unnamed: Q1.1 (G), Q2.1 (G), U4.13 (OUTC)
unnamed: Q1.2 (D), Q2.2 (D)
unnamed: Q2.3 (S), R26.1, U5.5
unnamed: Q3.1 (G), Q4.1 (G), U4.14 (OUTB)
unnamed: Q3.2 (D), Q4.2 (D)
unnamed: Q4.3 (S), R26.2, R27.1
unnamed: Q5.1 (G), Q6.1 (G), U4.15 (OUTA)
unnamed: Q5.2 (D), Q6.2 (D)
unnamed: Q6.3 (S), R27.2, R29.1
unnamed: R20.2, R21.2, R22.2, R23.2, TP4.1, U1.5, U2.7
unnamed: R21.1, U1.10
unnamed: R22.1, U1.12
unnamed: R23.1, U1.13, U1.15
unnamed: R25.2, U4.5 (En), U4.11 (Sense-), U4.16 (UVLO/Stby)
unnamed: TP5.1, U1.7, U5.6

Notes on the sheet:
10mA
1mA
100uA
10uA
current input

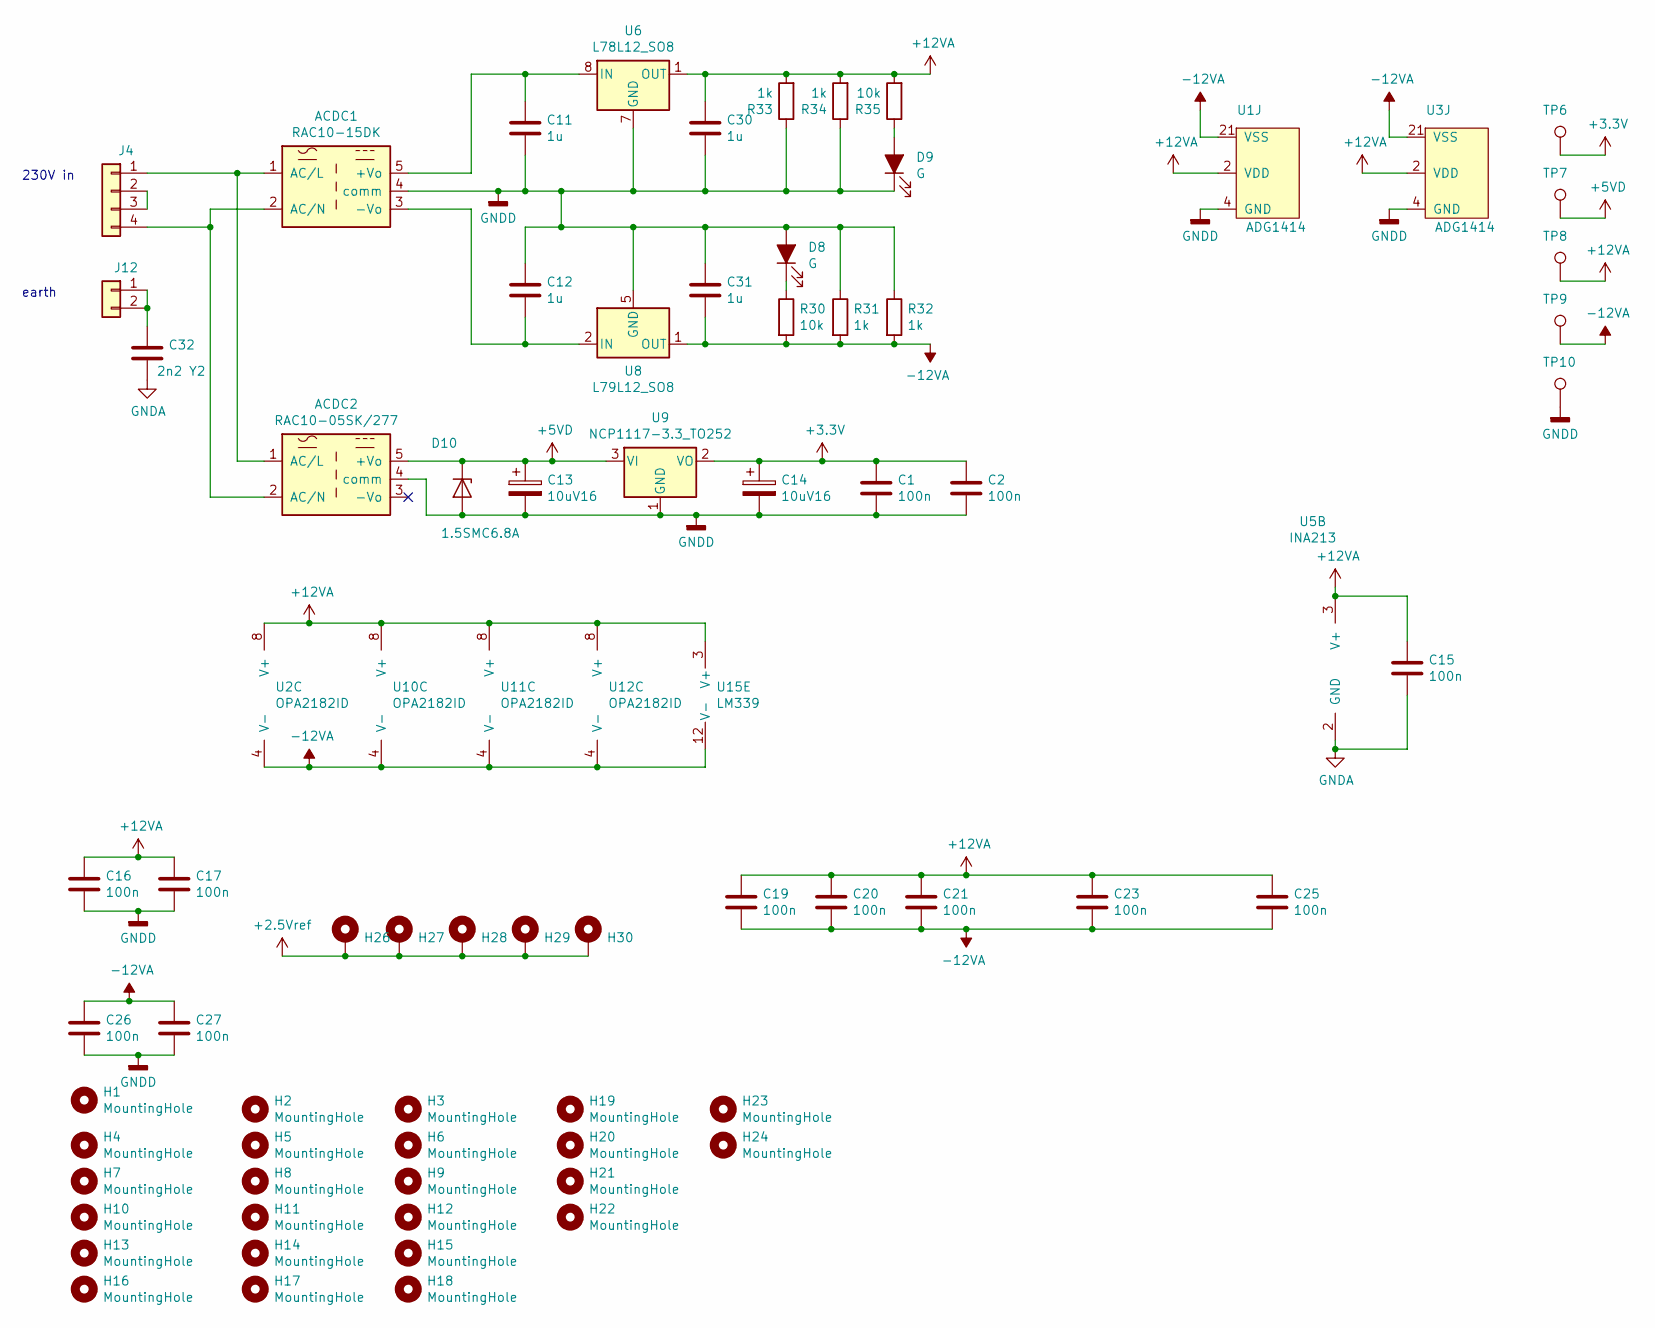
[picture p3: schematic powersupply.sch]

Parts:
ACDC1: RAC10-15DK; RAC10
ACDC2: RAC10-05SK/277; RAC10
C1, C2, C15, C16, C17, C19, C20, C21, C23, C25, C26, C27: 100n; C_0805_2012Metric_Pad1.15x1.40mm_HandSolder
C11, C12, C30, C31: 1u; C_0805_2012Metric_Pad1.15x1.40mm_HandSolder
C13, C14: 10uV16; CP_Radial_D5.0mm_P2.00mm
C32: 2n2 Y2; C_Rect_L13.0mm_W4.0mm_P10.00mm_FKS3_FKP3_MKS4
D8, D9: G; LED_0805_2012Metric_Pad1.15x1.40mm_HandSolder
D10: 1.5SMC6.8A; D_SMC
H1, H2, H3, H4, H5, H6, H7, H8, H9, H10, H11, H12, H13, H14, H15, H16, H17, H18, H19, H20, H21, H22, H23, H24: MountingHole; MountingHole_3.1mm_M3
H26, H27, H28, H29, H30: MountingHole_Pad; MountingHole_3.2mm_M3_DIN965_Pad
J4: Conn_01x06; PhoenixContact_MSTBVA_2,5_4-G_1x04_P5.00mm_Vertical
J12: Conn_01x02; PhoenixContact_MSTBVA_2,5_2-G_1x02_P5.00mm_Vertical
R30, R35: 10k; R_1206_3216Metric_Pad1.42x1.75mm_HandSolder
R31, R32, R33, R34: 1k; R_1206_3216Metric_Pad1.42x1.75mm_HandSolder
TP6, TP7, TP8, TP9, TP10: TestPoint; TestPoint_THTPad_2.0x2.0mm_Drill1.0mm
U1, U3: ADG1414; TSSOP-24_4.4x7.8mm_P0.65mm
U2, U10, U11, U12: OPA2182ID; SO-8_3.9x4.9mm_P1.27mm
U5: INA213; Texas_R_PDSO-G6
U6: L78L12_SO8; SOIC-8_3.9x4.9mm_P1.27mm
U8: L79L12_SO8; SOIC-8_3.9x4.9mm_P1.27mm
U9: NCP1117-3.3_TO252; TO-252-2
U15: LM339; SOIC-14_3.9x8.7mm_P1.27mm

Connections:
+1V0: H26.1, H27.1, H28.1, H29.1, H30.1; also elsewhere on the board
+3V3: C1.1, C2.1, C14.1, TP6.1, U9.2 (VO); also elsewhere on the board
+5VD: ACDC2.5 (+Vo), C13.1, D10.1 (K), TP7.1, U9.3 (VI); also elsewhere on the board
+12VA: C15.1, C16.1, C17.1, C19.1, C20.1, C21.1, C23.1, C25.1, C30.1, R33.2, R34.2, R35.2, TP8.1, U1.2 (VDD), U2.8 (V+), U3.2 (VDD), U5.3 (V+), U6.1 (OUT), U10.8 (V+), U11.8 (V+), U12.8 (V+), U15.3 (V+); also elsewhere on the board
-12VA: C19.2, C20.2, C21.2, C23.2, C25.2, C26.1, C27.1, C31.2, R30.2, R31.2, R32.2, TP9.1, U1.21 (VSS), U2.4 (V-), U3.21 (VSS), U8.1 (OUT), U10.4 (V-), U11.4 (V-), U12.4 (V-), U15.12 (V-); also elsewhere on the board
GNDA: C15.2, C32.2, U5.2 (GND); also elsewhere on the board
GNDD: ACDC1.4 (comm), ACDC2.4 (comm), C1.2, C2.2, C11.2, C12.1, C13.2, C14.2, C16.2, C17.2, C26.2, C27.2, C30.2, C31.1, D8.2 (A), D9.1 (K), D10.2 (A), R31.1, R32.1, R33.1, R34.1, TP10.1, U1.4 (GND), U3.4 (GND), U6.2 (GND), U6.3 (GND), U6.6 (GND), U6.7 (GND), U8.5 (GND), U9.1 (GND); also elsewhere on the board
unnamed: ACDC1.1 (AC/L), ACDC2.1 (AC/L), J4.1
unnamed: ACDC1.2 (AC/N), ACDC2.2 (AC/N), J4.4
unnamed: ACDC1.3 (-Vo), C12.2, U8.2 (IN), U8.3 (IN), U8.6 (IN), U8.7 (IN)
unnamed: ACDC1.5 (+Vo), C11.1, U6.8 (IN)
unnamed: C32.1, J12.1, J12.2
unnamed: D8.1 (K), R30.1
unnamed: D9.2 (A), R35.1
unnamed: J4.2, J4.3

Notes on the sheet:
230V in
earth

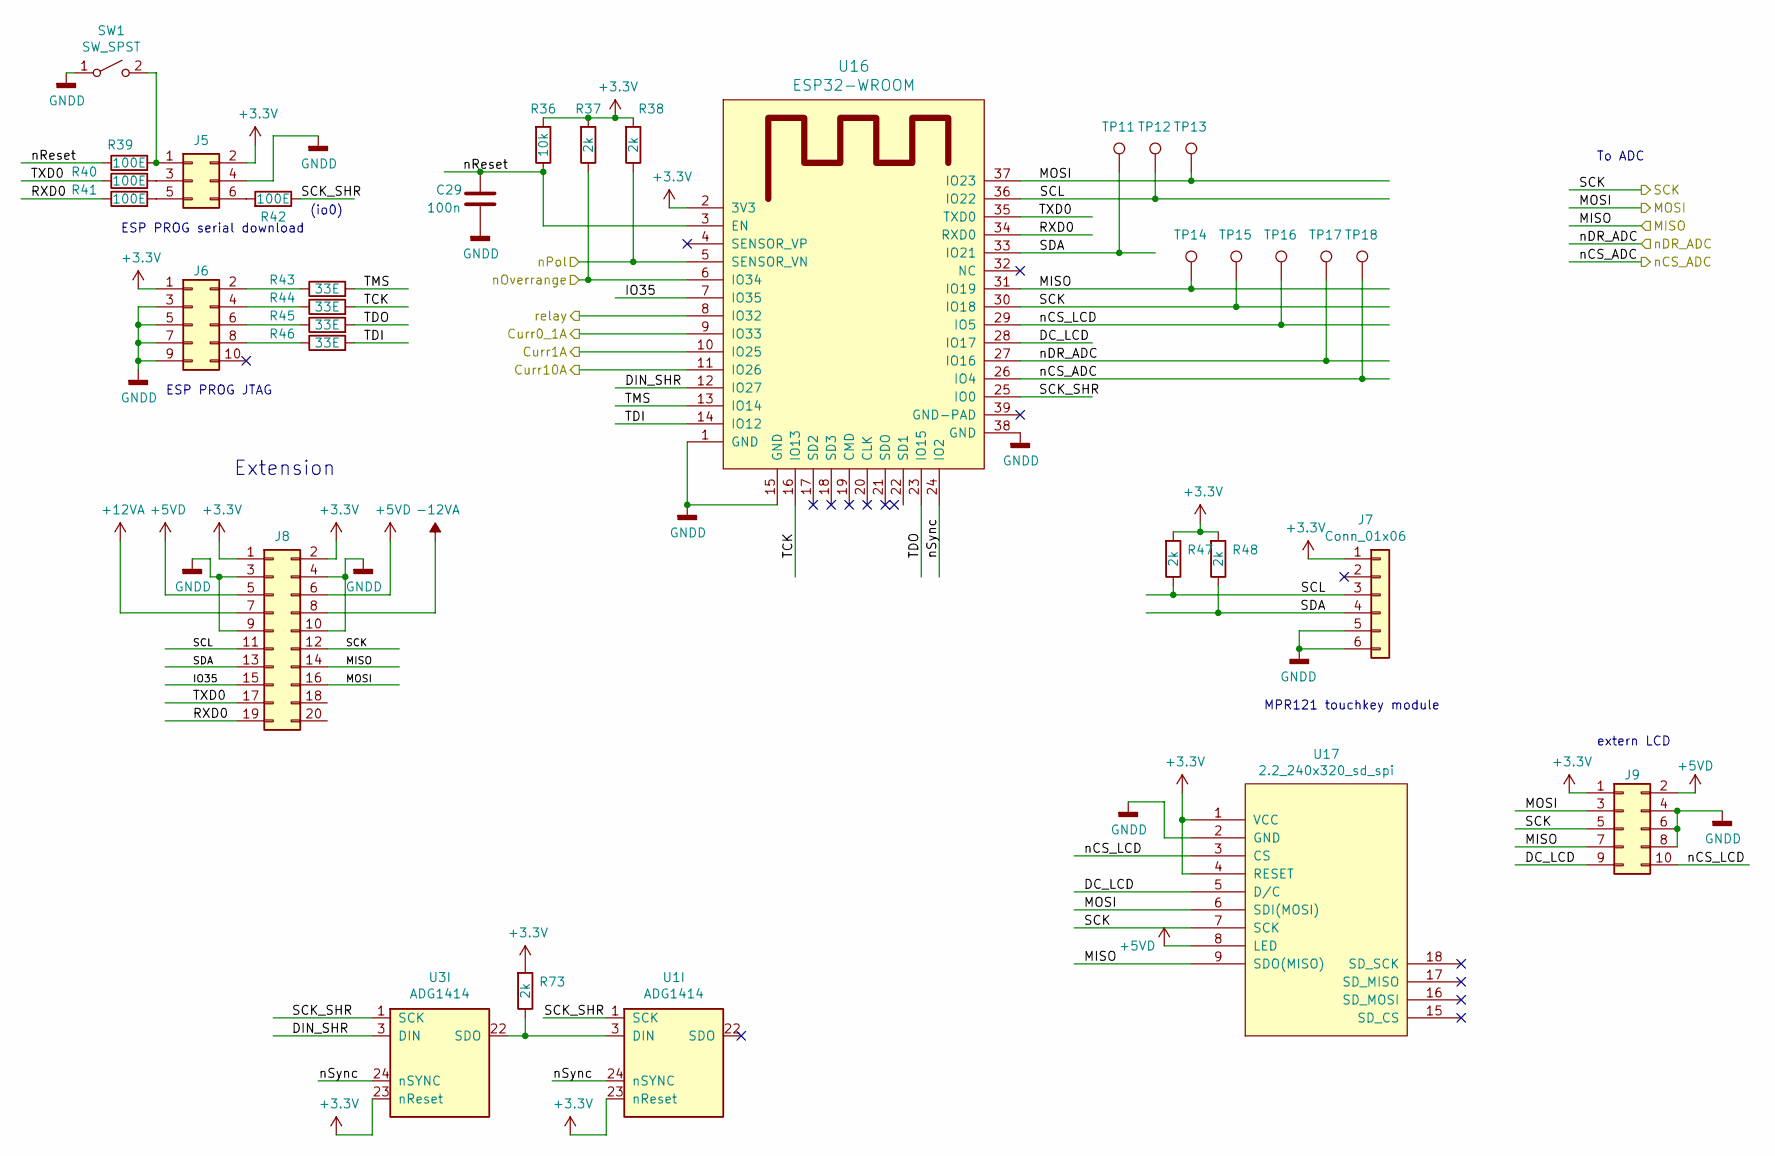
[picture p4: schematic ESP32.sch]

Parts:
C29: 100n; C_0805_2012Metric_Pad1.15x1.40mm_HandSolder
J5: bozed header 6p; IDC-Header_2x03_P2.54mm_Vertical
J6, J9: boxed header 2x5; IDC-Header_2x05_P2.54mm_Vertical
J7: Conn_01x06; PinHeader_1x06_P2.54mm_Vertical
J8: Conn_02x10_Odd_Even; IDC-Header_2x10_P2.54mm_Vertical
R36: 10k; R_0805_2012Metric_Pad1.15x1.40mm_HandSolder
R37, R38, R47, R48, R73: 2k; R_0805_2012Metric_Pad1.15x1.40mm_HandSolder
R39, R40, R41, R42: 100E; R_0805_2012Metric_Pad1.15x1.40mm_HandSolder
R43, R44, R45, R46: 33E; R_0805_2012Metric_Pad1.15x1.40mm_HandSolder
SW1: SW_SPST; SW_PUSH_6mm
TP11, TP12, TP13, TP14, TP15, TP16, TP17, TP18: TestPoint; TestPoint_THTPad_2.0x2.0mm_Drill1.0mm
U1, U3: ADG1414; TSSOP-24_4.4x7.8mm_P0.65mm
U16: ESP32-WROOM
U17: 2.2_240x320_sd_spi; 2.2_tft_240x320_sd_spi

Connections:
+3V3: J5.2, J6.1, J7.1, J8.1, J8.2, J9.1, R36.2, R37.2, R38.2, R47.2, R48.2, R73.2, U1.23 (nReset), U3.23 (nReset), U16.2 (3V3), U17.1 (VCC), U17.4 (RESET); also elsewhere on the board
+5VD: J8.5, J8.6, J9.2, U17.8 (LED); also elsewhere on the board
+12VA: J8.7; also elsewhere on the board
-12VA: J8.8; also elsewhere on the board
/ADC/MISO: J8.14, J9.7, TP14.1, U16.31 (IO19), U17.9 (SDO(MISO)); also elsewhere on the board
/ADC/MOSI: J8.16, J9.3, TP13.1, U16.37 (IO23), U17.6 (SDI(MOSI)); also elsewhere on the board
/ADC/SCK: J8.12, J9.5, TP15.1, U16.30 (IO18), U17.7 (SCK); also elsewhere on the board
/ADC/nCS_ADC: TP18.1, U16.26 (IO4); also elsewhere on the board
/ADC/nDR_ADC: TP17.1, U16.27 (IO16); also elsewhere on the board
/ESP32/Curr0_1A: U16.9 (IO33); also elsewhere on the board
/ESP32/Curr1A: U16.10 (IO25); also elsewhere on the board
/ESP32/Curr10A: U16.11 (IO26); also elsewhere on the board
/ESP32/DC_LCD: J9.9, U16.28 (IO17), U17.5 (D/C)
/ESP32/DIN_SHR: U3.3 (DIN), U16.12 (IO27)
/ESP32/IO35: J8.15, U16.7 (IO35)
/ESP32/RXD0: J8.19, R41.1, U16.34 (RXD0)
/ESP32/SCK_SHR: R42.1, U1.1 (SCK), U3.1 (SCK), U16.25 (IO0)
/ESP32/SCL: J7.3, J8.11, R47.1, TP12.1, U16.36 (IO22)
/ESP32/SDA: J7.4, J8.13, R48.1, TP11.1, U16.33 (IO21)
/ESP32/TCK: R44.2, U16.16 (IO13)
/ESP32/TDI: R46.2, U16.14 (IO12)
/ESP32/TDO: R45.2, U16.23 (IO15)
/ESP32/TMS: R43.2, U16.13 (IO14)
/ESP32/TXD0: J8.17, R40.1, U16.35 (TXD0)
/ESP32/nCS_LCD: J9.10, TP16.1, U16.29 (IO5), U17.3 (CS)
/ESP32/nOverrange: R37.1, U16.6 (IO34); also elsewhere on the board
/ESP32/nPol: R38.1, U16.5 (SENSOR_VN); also elsewhere on the board
/ESP32/nReset: C29.1, R36.1, R39.1, U16.3 (EN)
/ESP32/nSync: U1.24 (nSYNC), U3.24 (nSYNC), U16.24 (IO2)
/ESP32/relay: U16.8 (IO32); also elsewhere on the board
GNDD: C29.2, J5.4, J6.3, J6.5, J6.7, J6.9, J7.5, J7.6, J8.3, J8.4, J8.9, J8.10, J9.4, J9.6, J9.8, SW1.1 (A), U16.1 (GND), U16.15 (GND), U16.38 (GND), U17.2 (GND); also elsewhere on the board
unnamed: J5.1, R39.2, SW1.2 (B)
unnamed: J5.3, R40.2
unnamed: J5.5, R41.2
unnamed: J5.6, R42.2
unnamed: J6.2, R43.1
unnamed: J6.4, R44.1
unnamed: J6.6, R45.1
unnamed: J6.8, R46.1
unnamed: R73.1, U1.3 (DIN), U3.22 (SDO)

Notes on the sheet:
ESP PROG JTAG
ESP PROG serial download
MPR121 touchkey module
To ADC
Extension
extern LCD
(io0)

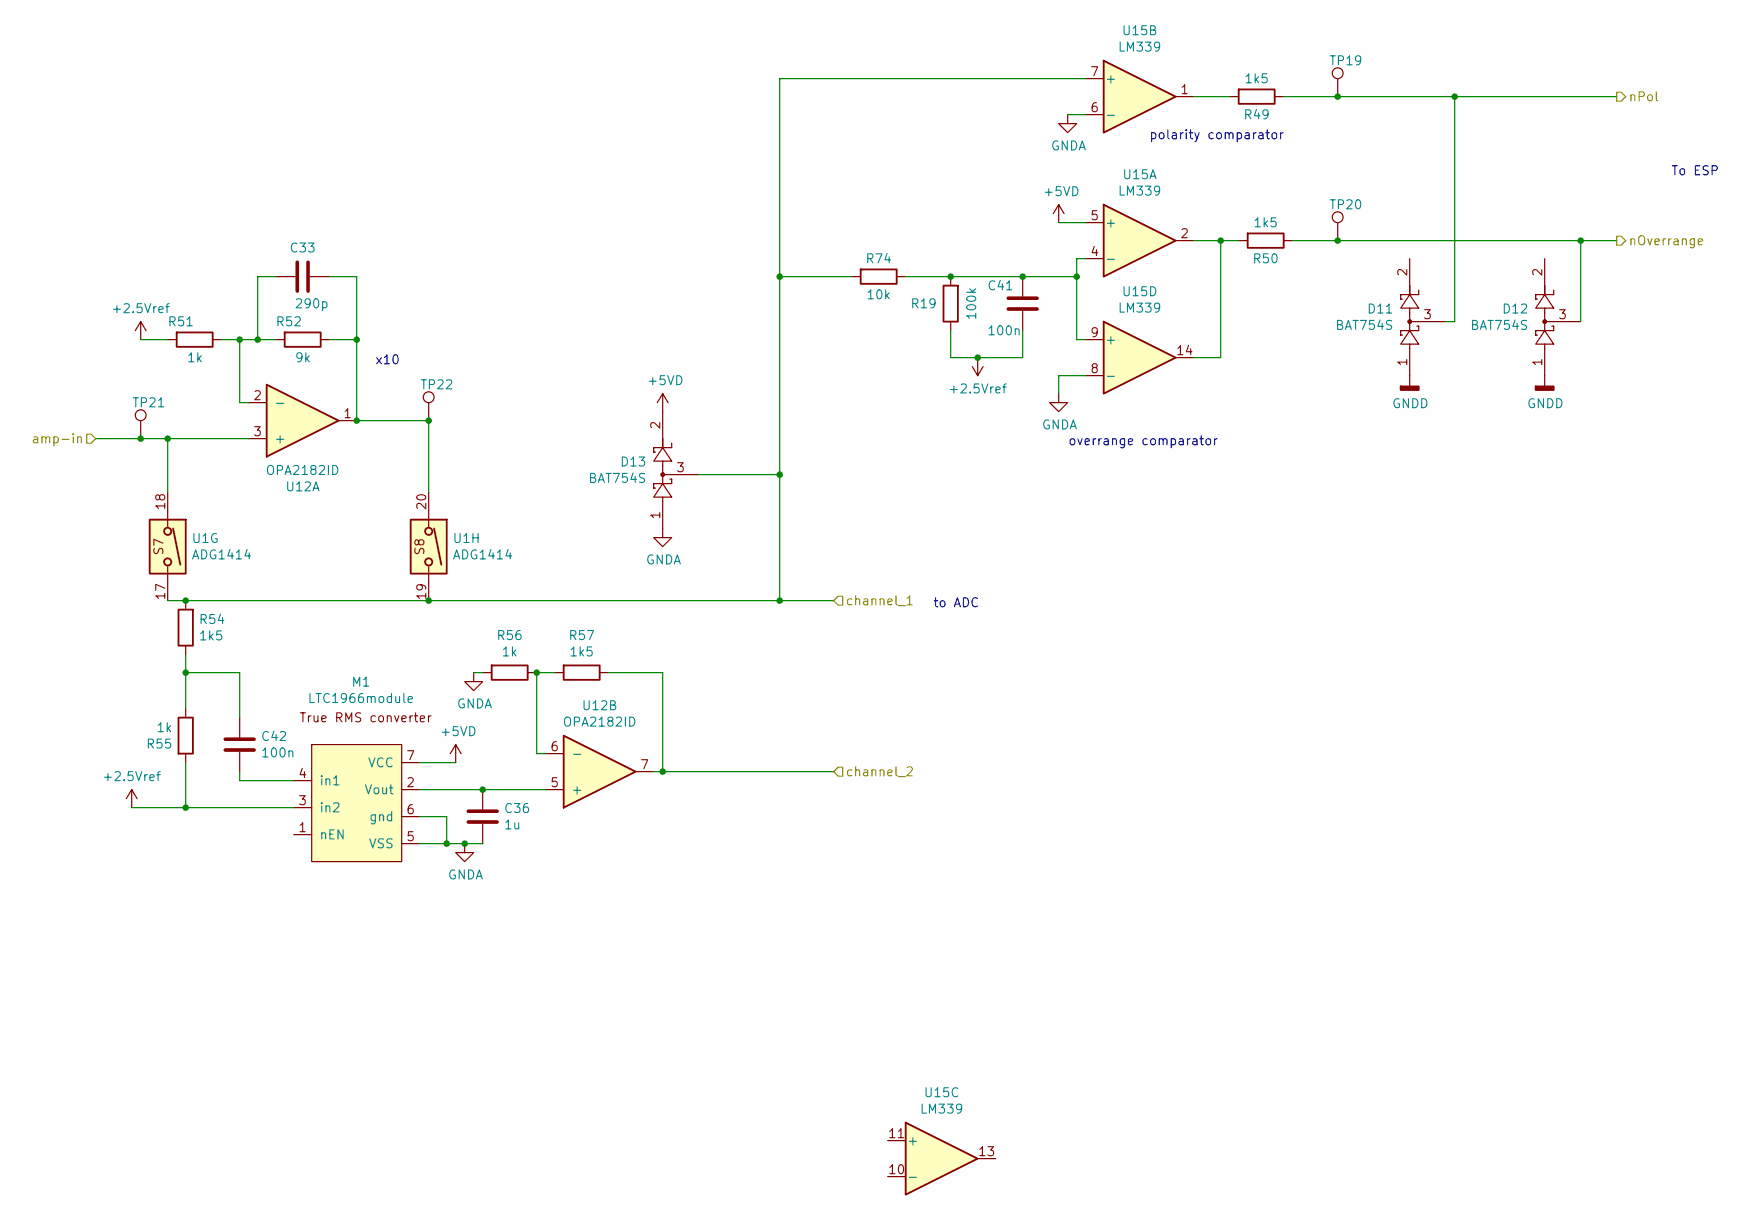
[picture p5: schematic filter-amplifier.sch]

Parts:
C33: 290p; C_Disc_D3.0mm_W2.0mm_P2.50mm
C36: 1u; C_0805_2012Metric_Pad1.15x1.40mm_HandSolder
C41, C42: 100n; C_0805_2012Metric_Pad1.15x1.40mm_HandSolder
D11, D12, D13: BAT754S; SOT-23-handsolder
M1: LTC1966module; ltc1966module
R19: 100k; R_0805_2012Metric_Pad1.15x1.40mm_HandSolder
R49, R50, R54, R57: 1k5; R_0805_2012Metric_Pad1.15x1.40mm_HandSolder
R51, R55, R56: 1k; R_0805_2012Metric_Pad1.15x1.40mm_HandSolder
R52: 9k; R_0805_2012Metric_Pad1.15x1.40mm_HandSolder
R74: 10k; R_0805_2012Metric_Pad1.15x1.40mm_HandSolder
TP19, TP20, TP21, TP22: TestPoint; TestPoint_THTPad_2.0x2.0mm_Drill1.0mm
U1: ADG1414; TSSOP-24_4.4x7.8mm_P0.65mm
U12: OPA2182ID; SO-8_3.9x4.9mm_P1.27mm
U15: LM339; SOIC-14_3.9x8.7mm_P1.27mm

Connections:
+1V0: C41.2, M1.3 (in2), R19.1, R51.2, R55.2; also elsewhere on the board
+5VD: D13.2, M1.7 (VCC), U15.5 (+); also elsewhere on the board
/ADC/channel_1: D13.3, R54.2, R74.2, U1.17, U1.19, U15.7 (+); also elsewhere on the board
/ADC/channel_2: R57.1, U12.7; also elsewhere on the board
/ESP32/nOverrange: D12.3, R50.1, TP20.1; also elsewhere on the board
/ESP32/nPol: D11.3, R49.1, TP19.1; also elsewhere on the board
/filter-amplifier/amp-in: TP21.1, U1.18, U12.3 (+); also elsewhere on the board
GNDA: C36.2, D13.1, M1.5 (VSS), M1.6 (gnd), R56.2, U15.6 (-), U15.8 (-); also elsewhere on the board
GNDD: D11.1, D12.1; also elsewhere on the board
unnamed: C33.1, R52.1, TP22.1, U1.20, U12.1
unnamed: C33.2, R51.1, R52.2, U12.2 (-)
unnamed: C36.1, M1.2 (Vout), U12.5 (+)
unnamed: C41.1, R19.2, R74.1, U15.4 (-), U15.9 (+)
unnamed: C42.1, R54.1, R55.1
unnamed: C42.2, M1.4 (in1)
unnamed: R49.2, U15.1
unnamed: R50.2, U15.2, U15.14
unnamed: R56.1, R57.2, U12.6 (-)

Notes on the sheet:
x10
overrange comparator
to ADC
polarity comparator
To ESP

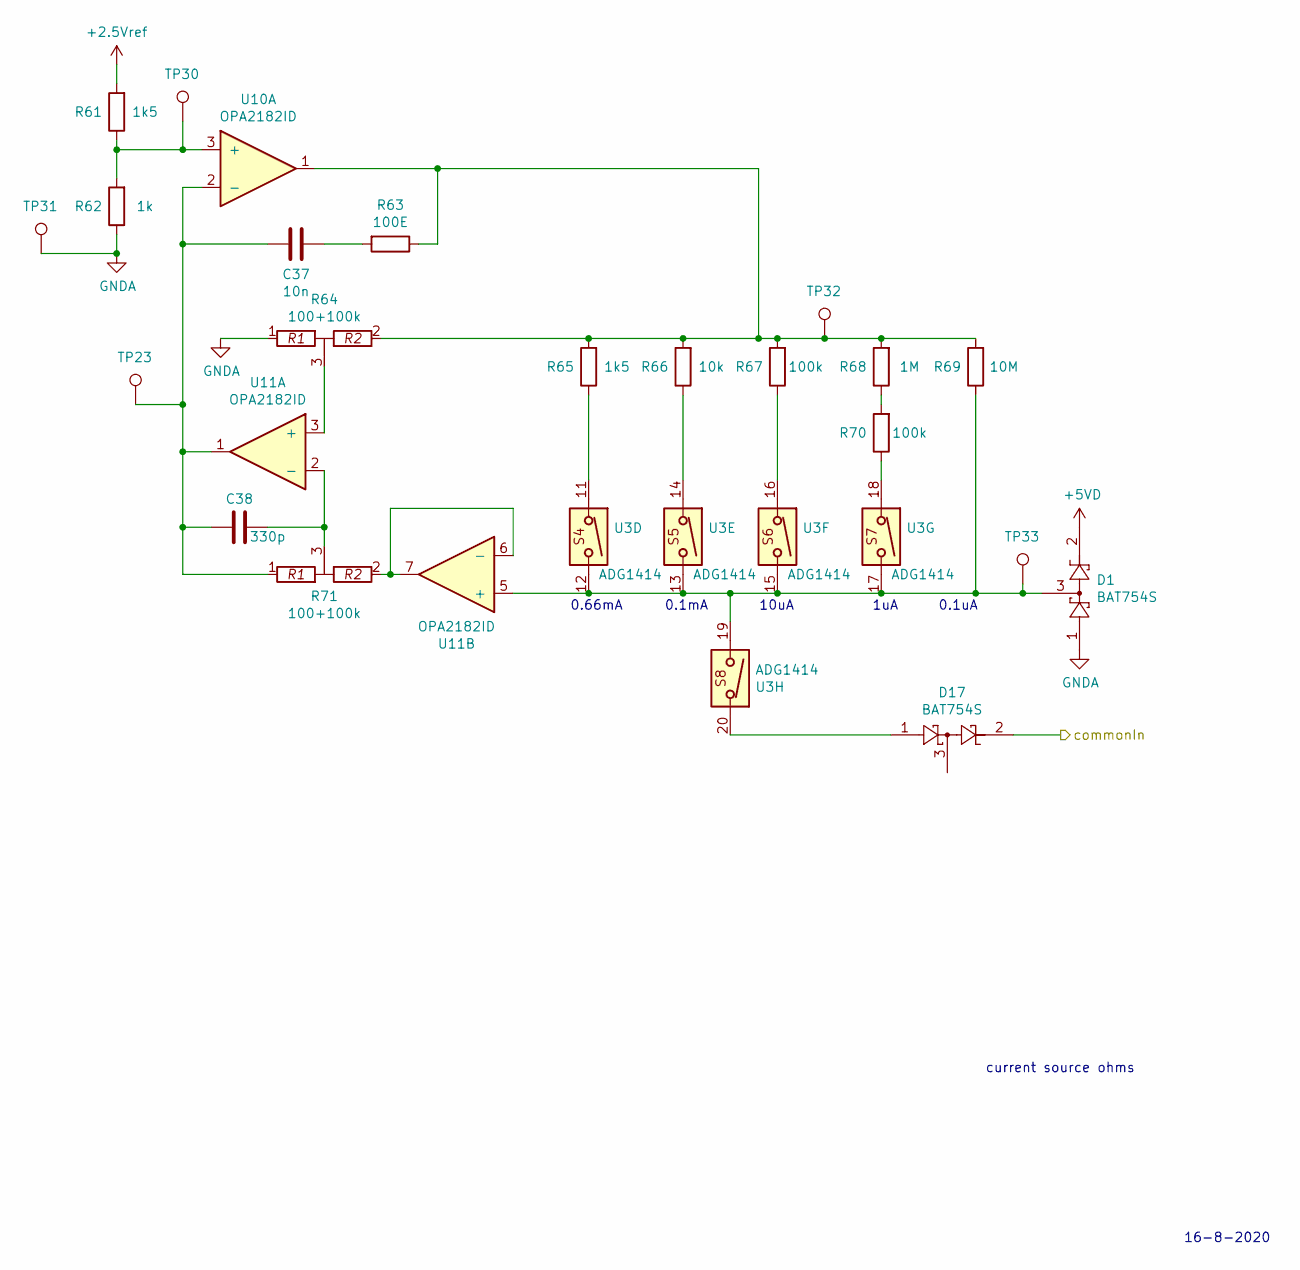
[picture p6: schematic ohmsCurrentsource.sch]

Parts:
C37: 10n; C_0805_2012Metric_Pad1.15x1.40mm_HandSolder
C38: 330p; C_0805_2012Metric_Pad1.15x1.40mm_HandSolder
D1, D17: BAT754S; SOT-23-handsolder
R61, R65: 1k5; R_0805_2012Metric_Pad1.15x1.40mm_HandSolder
R62: 1k; R_0805_2012Metric_Pad1.15x1.40mm_HandSolder
R63: 100E; R_0805_2012Metric_Pad1.15x1.40mm_HandSolder
R64, R71: 100+100k; SOT-23
R66: 10k; R_0805_2012Metric_Pad1.15x1.40mm_HandSolder
R67, R70: 100k; R_0805_2012Metric_Pad1.15x1.40mm_HandSolder
R68: 1M; R_0805_2012Metric_Pad1.15x1.40mm_HandSolder
R69: 10M; R_0805_2012Metric_Pad1.15x1.40mm_HandSolder
TP23, TP30, TP31, TP32, TP33: TestPoint; TestPoint_THTPad_2.0x2.0mm_Drill1.0mm
U3: ADG1414; TSSOP-24_4.4x7.8mm_P0.65mm
U10, U11: OPA2182ID; SO-8_3.9x4.9mm_P1.27mm

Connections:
+1V0: R61.2; also elsewhere on the board
+5VD: D1.2; also elsewhere on the board
/VoltInput/commonIn: D17.2; also elsewhere on the board
GNDA: D1.1, R62.1, R64.1, TP31.1; also elsewhere on the board
unnamed: C37.1, C38.1, R71.1, TP23.1, U10.2 (-), U11.1
unnamed: C37.2, R63.2
unnamed: C38.2, R71.3, U11.2 (-)
unnamed: D1.3, R69.1, TP33.1, U3.12, U3.13, U3.15, U3.17, U3.19, U11.5 (+)
unnamed: D17.1, U3.20
unnamed: R61.1, R62.2, TP30.1, U10.3 (+)
unnamed: R63.1, R64.2, R65.2, R66.2, R67.2, R68.2, R69.2, TP32.1, U10.1
unnamed: R64.3, U11.3 (+)
unnamed: R65.1, U3.11
unnamed: R66.1, U3.14
unnamed: R67.1, U3.16
unnamed: R68.1, R70.2
unnamed: R70.1, U3.18
unnamed: R71.2, U11.6 (-), U11.7

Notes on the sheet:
current source ohms
0.66mA
0.1mA
10uA
1uA
0.1uA
16-8-2020

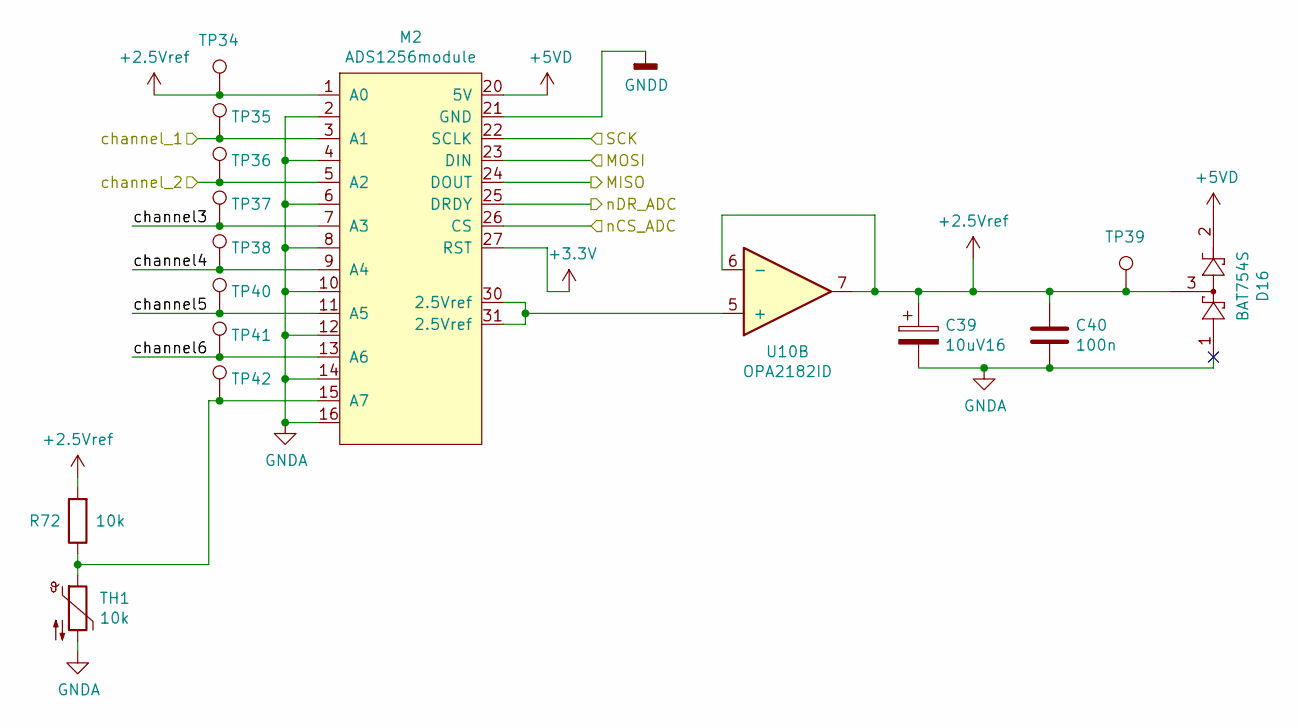
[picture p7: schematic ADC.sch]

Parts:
C39: 10uV16; CP_Radial_D5.0mm_P2.00mm
C40: 100n; C_0805_2012Metric_Pad1.15x1.40mm_HandSolder
D16: BAT754S; SOT-23-handsolder
M2: ADS1256module
R72: 10k; R_0805_2012Metric_Pad1.15x1.40mm_HandSolder
TH1: 10k; R_Axial_DIN0204_L3.6mm_D1.6mm_P2.54mm_Vertical
TP34, TP35, TP36, TP37, TP38, TP39, TP40, TP41, TP42: TestPoint; TestPoint_THTPad_2.0x2.0mm_Drill1.0mm
U10: OPA2182ID; SO-8_3.9x4.9mm_P1.27mm

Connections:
+1V0: C39.1, C40.1, D16.3, M2.1 (A0), R72.2, TP34.1, TP39.1, U10.6 (-), U10.7; also elsewhere on the board
+3V3: M2.27 (RST); also elsewhere on the board
+5VD: D16.2, M2.20 (5V); also elsewhere on the board
/ADC/MISO: M2.24 (DOUT); also elsewhere on the board
/ADC/MOSI: M2.23 (DIN); also elsewhere on the board
/ADC/SCK: M2.22 (SCLK); also elsewhere on the board
/ADC/channel3: M2.7 (A3), TP37.1
/ADC/channel4: M2.9 (A4), TP38.1
/ADC/channel5: M2.11 (A5), TP40.1
/ADC/channel6: M2.13 (A6), TP41.1
/ADC/channel_1: M2.3 (A1), TP35.1; also elsewhere on the board
/ADC/channel_2: M2.5 (A2), TP36.1; also elsewhere on the board
/ADC/nCS_ADC: M2.26 (CS); also elsewhere on the board
/ADC/nDR_ADC: M2.25 (DRDY); also elsewhere on the board
GNDA: C39.2, C40.2, D16.1, M2.2, M2.4, M2.6, M2.8, M2.10, M2.12, M2.14, M2.16, TH1.2; also elsewhere on the board
GNDD: M2.21 (GND); also elsewhere on the board
unnamed: M2.15 (A7), R72.1, TH1.1, TP42.1
unnamed: M2.30 (2.5Vref), M2.31 (2.5Vref), U10.5 (+)

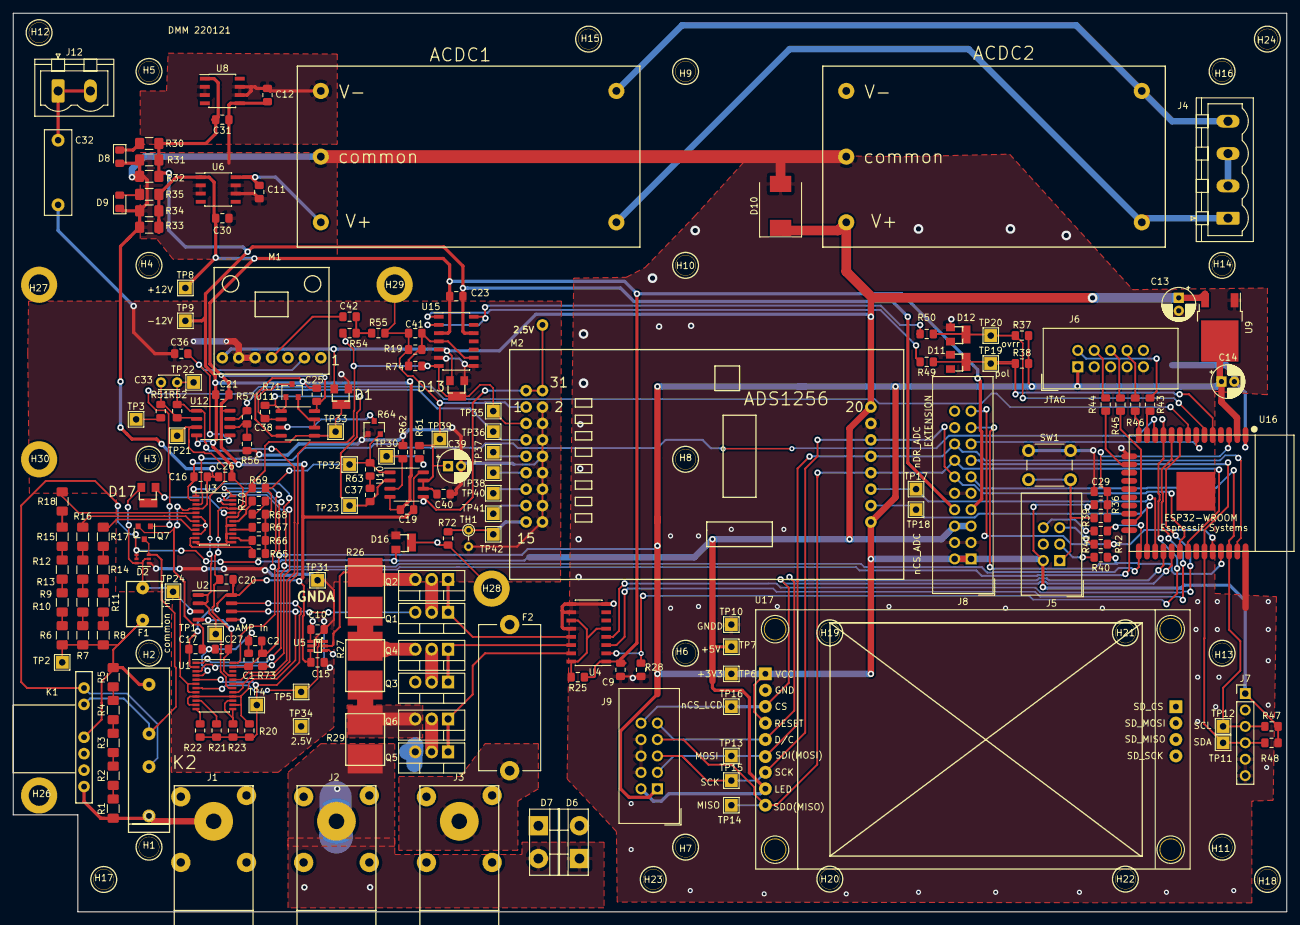
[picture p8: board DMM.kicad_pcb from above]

Board: 2 copper layers, 197.0 x 139.0 mm, 218 parts (0 on the bottom side), 120 nets.

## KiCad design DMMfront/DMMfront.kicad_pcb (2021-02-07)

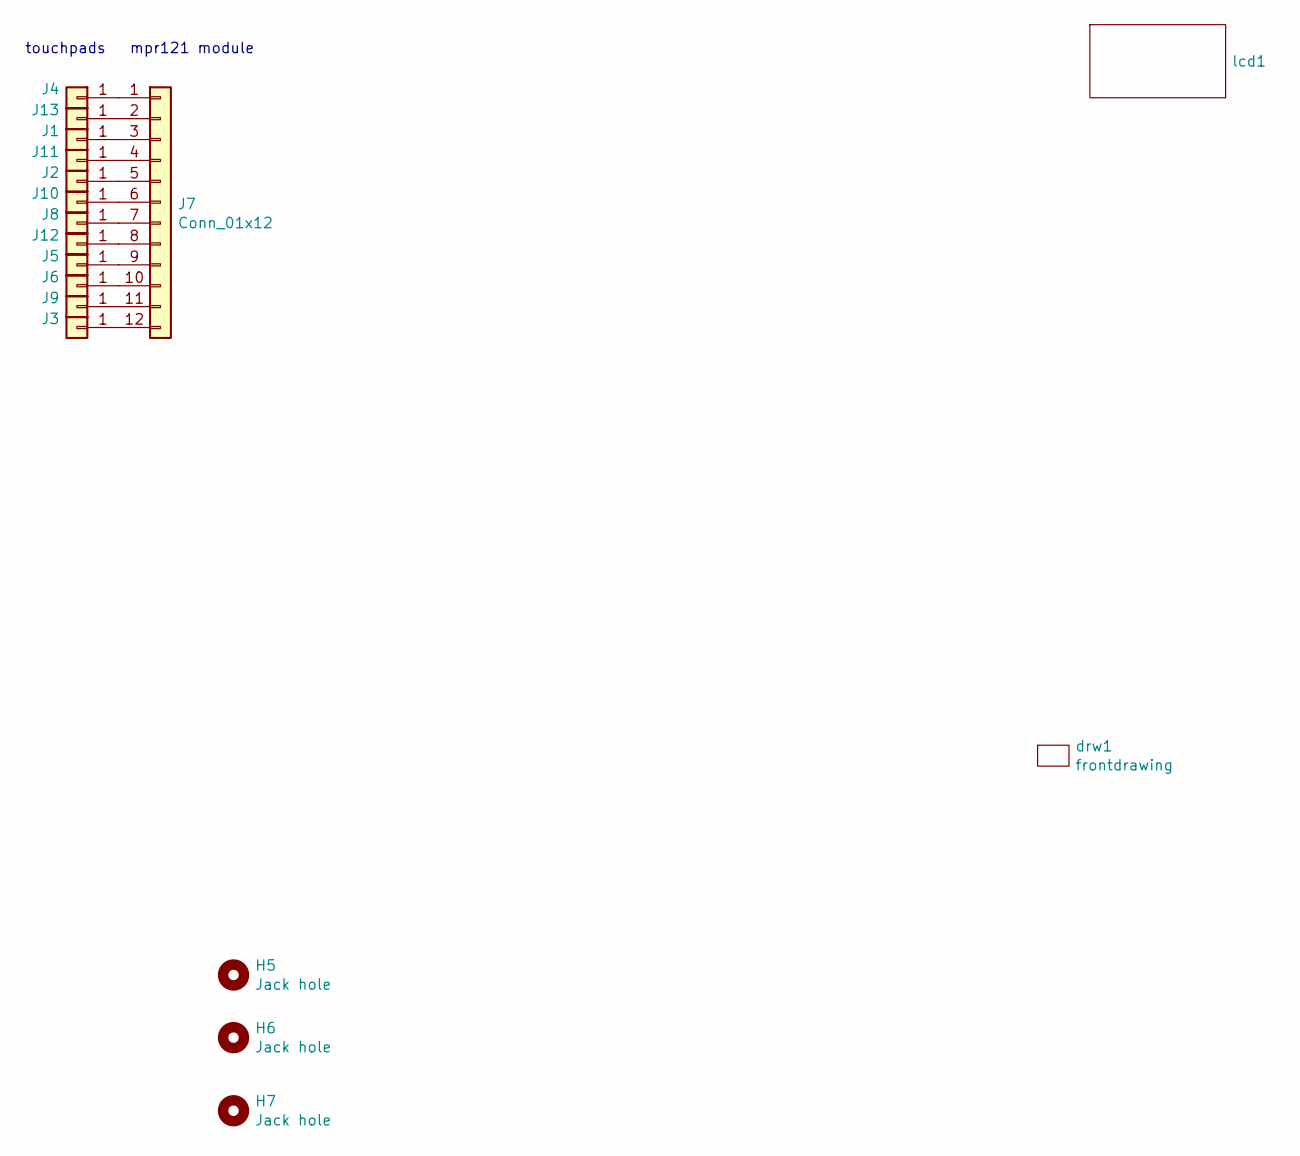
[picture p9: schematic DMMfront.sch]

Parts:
H5, H6, H7: Jack hole; hole11.5
J1, J2, J3, J4, J5, J6, J8, J9, J10, J11, J12, J13: Conn_01x01; touchpad10
J7: Conn_01x12; PinHeader_1x12_P2.54mm_Vertical_SMD_Pin1Right
drw1: frontdrawing; dmmfront
lcd1: lcdfront; 2.8_tft_front

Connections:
unnamed: J1.1, J7.3
unnamed: J2.1, J7.5
unnamed: J3.1, J7.12
unnamed: J4.1, J7.1
unnamed: J5.1, J7.9
unnamed: J6.1, J7.10
unnamed: J7.7, J8.1
unnamed: J7.11, J9.1
unnamed: J7.6, J10.1
unnamed: J7.4, J11.1
unnamed: J7.8, J12.1
unnamed: J7.2, J13.1

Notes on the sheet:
touchpads
mpr121 module

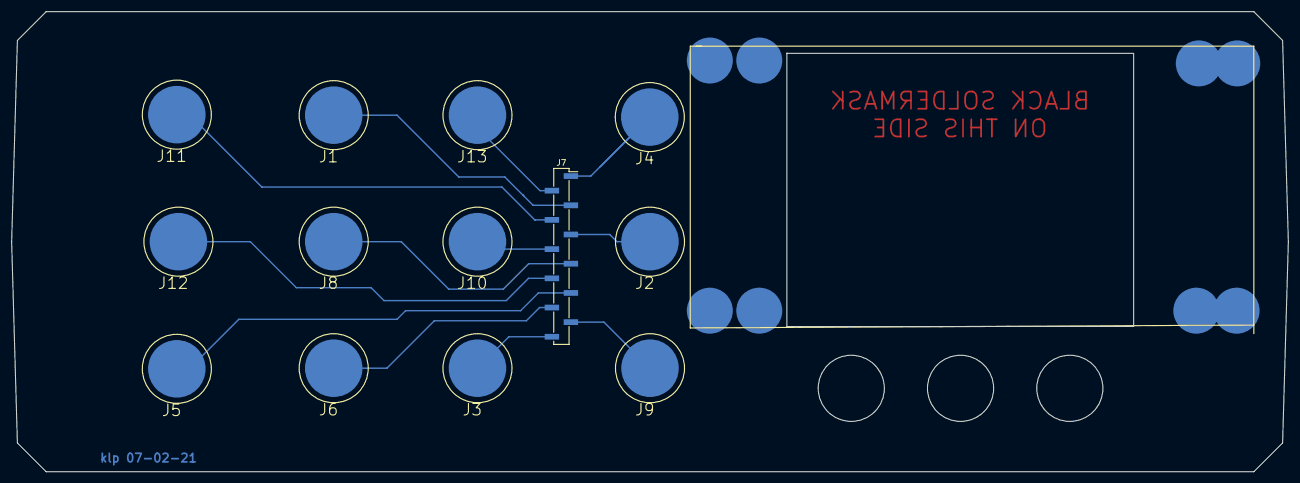
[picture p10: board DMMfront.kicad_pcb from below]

Board: 2 copper layers, 222.0 x 80.0 mm, 17 parts (13 on the bottom side), 12 nets.

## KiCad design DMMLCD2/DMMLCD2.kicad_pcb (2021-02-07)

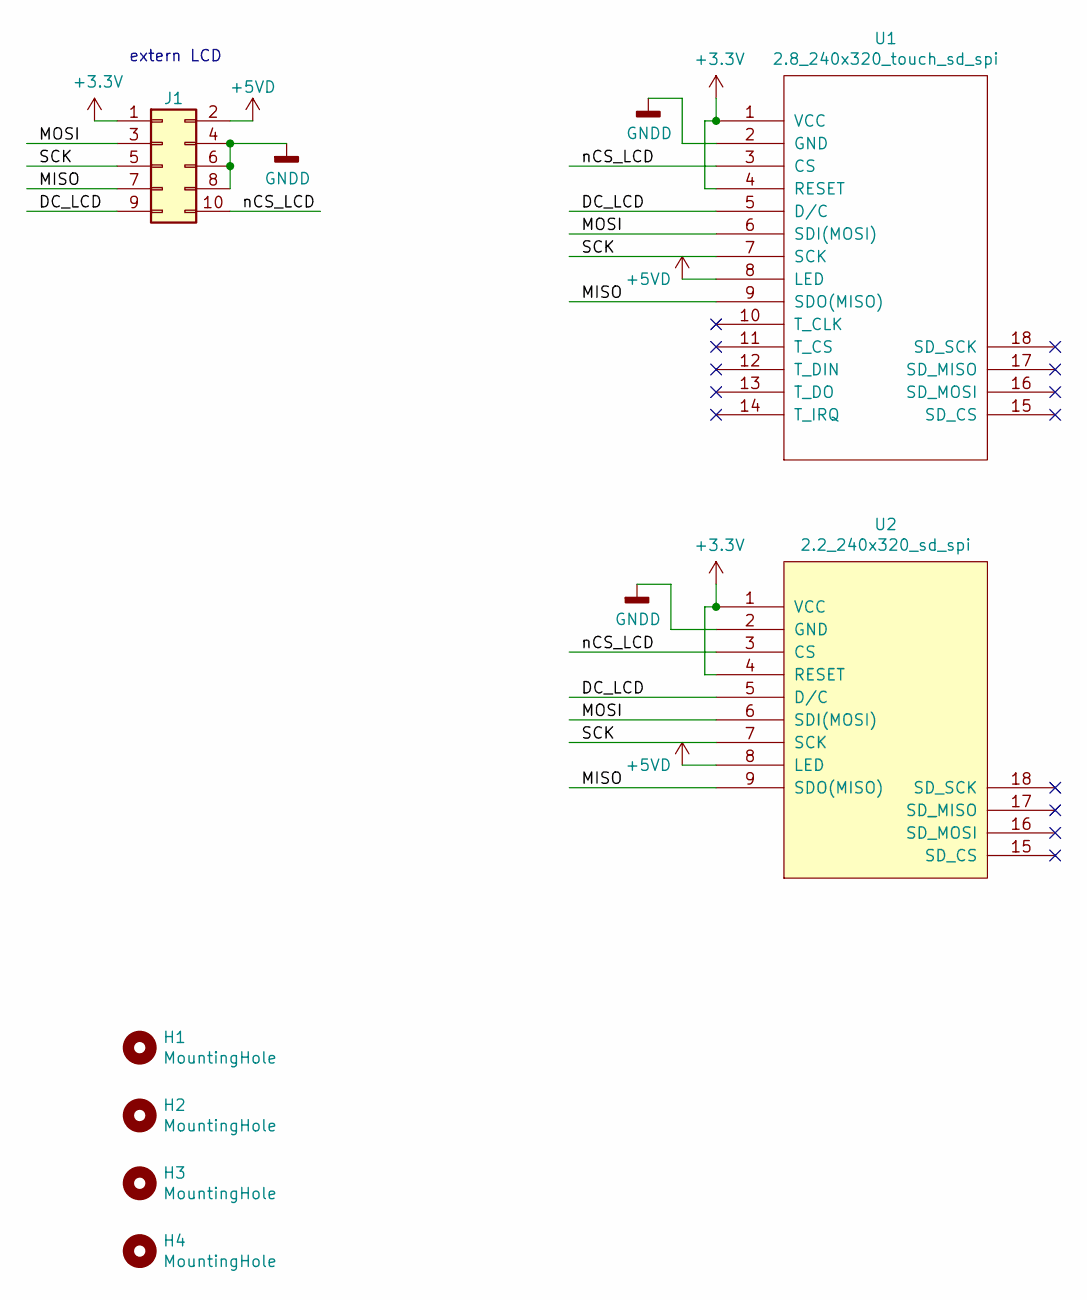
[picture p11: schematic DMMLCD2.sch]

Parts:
H1, H2, H3, H4: MountingHole; MountingHole_3.2mm_M3
J1: boxed header 2x5; IDC-Header_2x05_P2.54mm_Vertical
U1: 2.8_240x320_touch_sd_spi; 2.8_tft_240x320_touch_sd_spi
U2: 2.2_240x320_sd_spi; 2.2_tft_240x320_sd_spi

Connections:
+3V3: J1.1, U1.1 (VCC), U1.4 (RESET), U2.1 (VCC), U2.4 (RESET)
+5VD: J1.2, U1.8 (LED), U2.8 (LED)
/DC_LCD: J1.9, U1.5 (D/C), U2.5 (D/C)
/MISO: J1.7, U1.9 (SDO(MISO)), U2.9 (SDO(MISO))
/MOSI: J1.3, U1.6 (SDI(MOSI)), U2.6 (SDI(MOSI))
/SCK: J1.5, U1.7 (SCK), U2.7 (SCK)
/nCS_LCD: J1.10, U1.3 (CS), U2.3 (CS)
GNDD: J1.4, J1.6, J1.8, U1.2 (GND), U2.2 (GND)

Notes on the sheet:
extern LCD

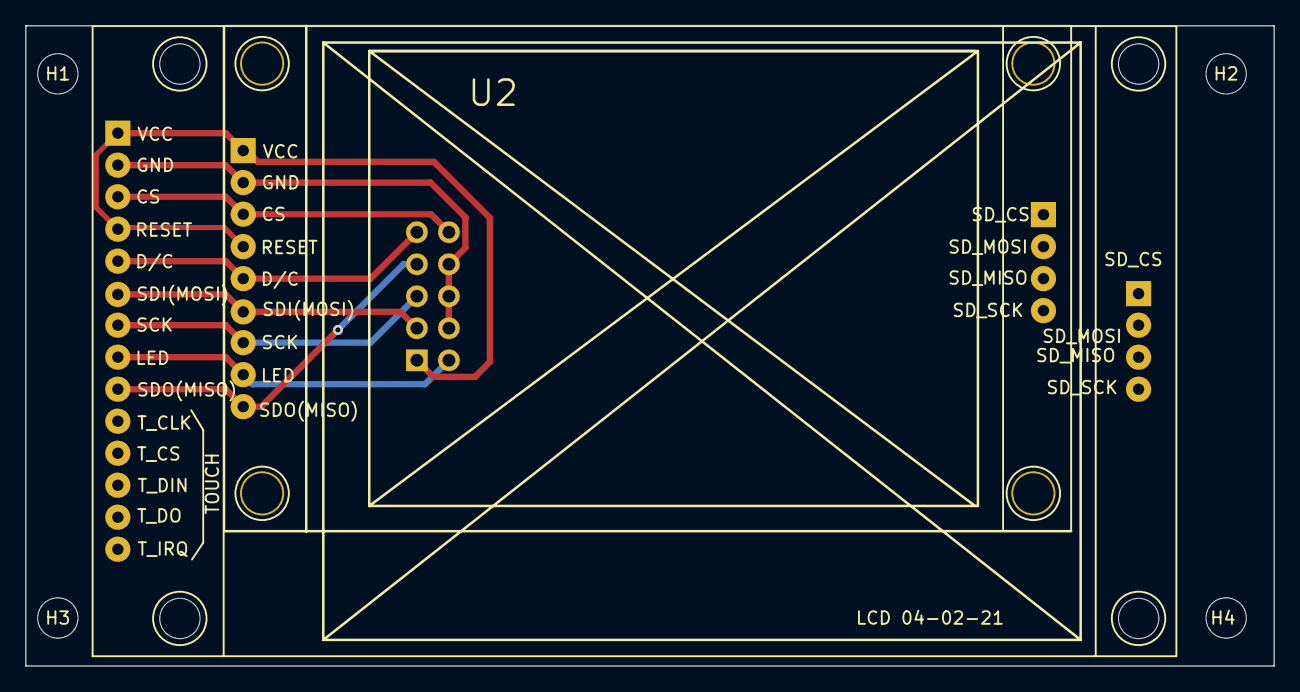
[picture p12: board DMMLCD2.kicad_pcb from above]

Board: 2 copper layers, 99.1 x 50.8 mm, 7 parts (1 on the bottom side), 8 nets.
